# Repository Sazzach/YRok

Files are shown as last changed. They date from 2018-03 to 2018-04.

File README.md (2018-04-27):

## Building

To build the firmware, first download the GNU ARM toolchain from: https://developer.arm.com/open-source/gnu-toolchain/gnu-rm/downloads and extract it into the root directory for this project. Then enter the firmware directory and use Make to build the firmware.

To see a video demonstration of our final project: https://photos.app.goo.gl/VnfEDqI2edRJLxgh1

## Pinout

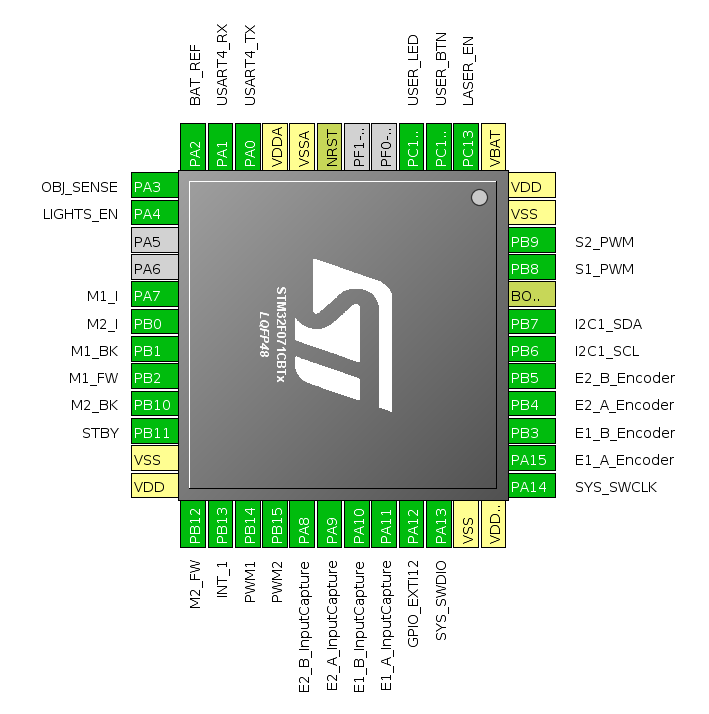
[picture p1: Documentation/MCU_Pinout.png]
STMF071CBTx pinout


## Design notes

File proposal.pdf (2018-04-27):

### CS5780 Project Proposal

Sam Zachary, Jeremy Whipple, Michael Zhang

Description:
We will build a robot that can balance on two parallel wheels with no external support. It will use a PID loop with an inertial measurement unit (LSM6DS3 IMU) (http://www.st.com/content/ccc/resource/technical/document/datasheet/a3/f5/4f/ae/8e/44/41/d7/DM00133076.pdf/files/DM00133076.pdf/jcr:content/translations/en.DM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) as input to control two motors (DAGU yellow gear motors). Each motor will potentially also be running its own PID loop to independently control speed. We will also have a custom designed microcontroller pcb (STM32F071) and motor encoder pcb. The motors, pcbs, and IMU will be mounted on a chassis fabricated out of laser cut wood and/or acrylic. Extraneous stretch goals include increased robustness, remote control, laser sensing.

The motor encoder PCB is mounted on the end of the DAGU gear motor. Each encoder has two IR reflectance sensors. These reflectance sensors sense transitions on a black and white encoder wheel mounted on the rear output shaft of the motor. To give a quadrature encoder signal, these sensors are positioned to emit signals 90 degrees out of phase from each other.

The custom microcontroller board collects all the necessary parts and peripherals (microprocessor, IMU, debug header, h-bridge, etc) and conforms to the Raspberry Pi HAT standard. It will connect to and control the two motors by reading from the motor encoders and running a PID control loop.

Implementation milestones:
1. PCB Design -- Sam
Solder board/make stencil for surface mount ICs -- Sam Simple board test (blinking LEDs) -- Michael
Design chassis - Sam
2. Communicate with IMU -- Jeremy
Serial communication -- Jeremy and Michael Correctly control motors -- Michael Construct chassis -- wood or acrylic -- Sam
3. Design algorithm to keep balance -- All
4. Tune algorithm -- All
Improve system reliability -- All

Functional block diagram:

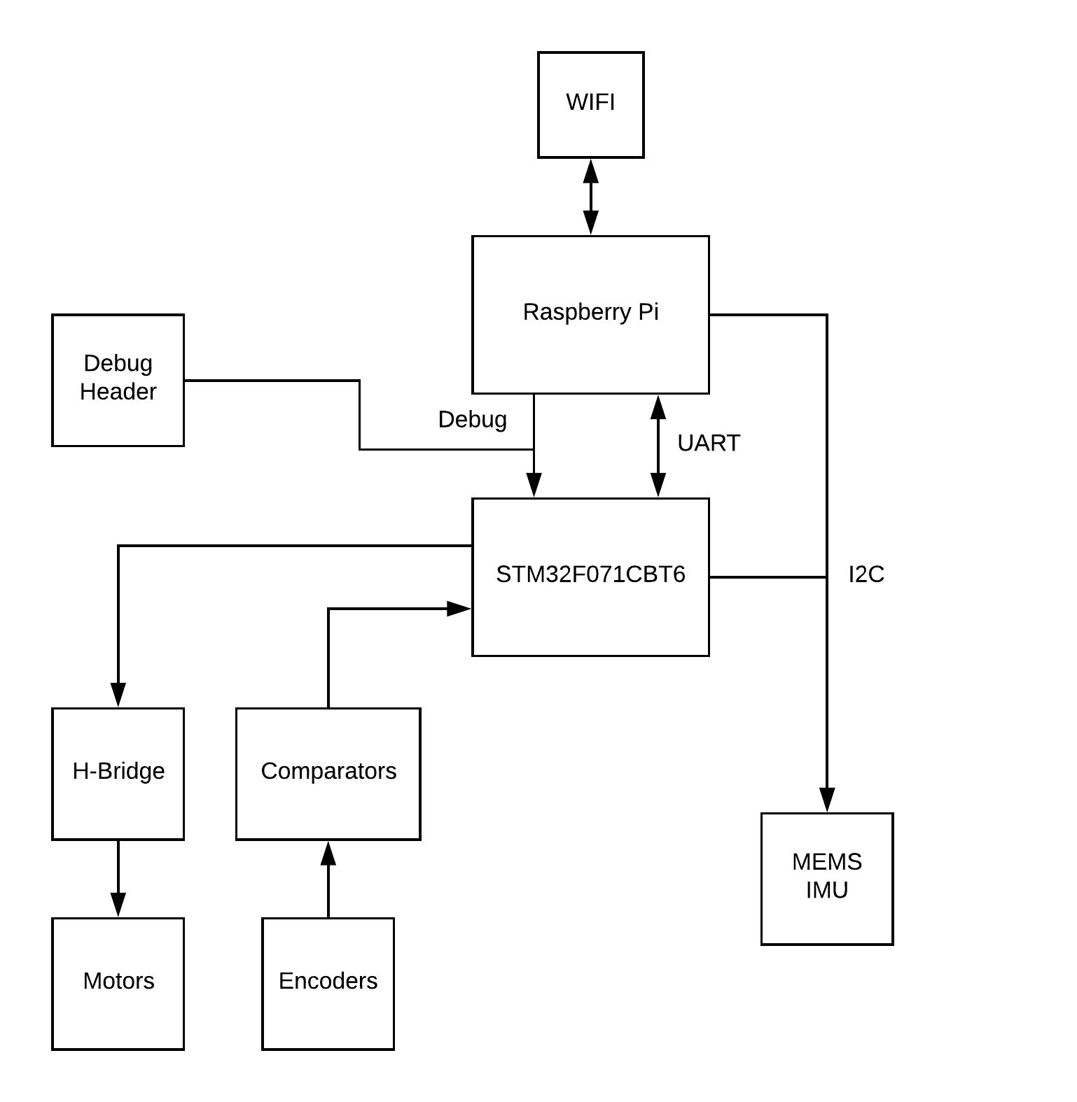
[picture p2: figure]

★ Raspberry pi passively used for wireless programming

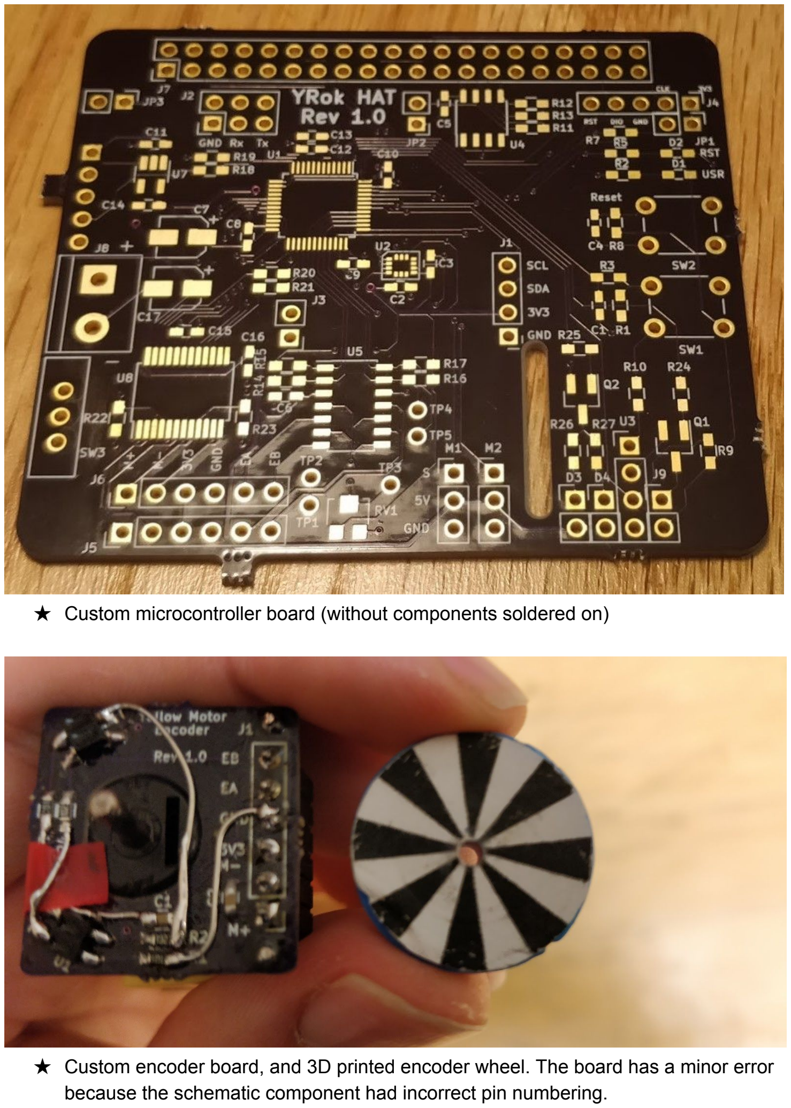
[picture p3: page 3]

★ Custom microcontroller board (without components soldered on)

★ Custom encoder board, and 3D printed encoder wheel. The board has a minor error because the schematic component had incorrect pin numbering.

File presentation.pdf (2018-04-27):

# CS 5780 Final Project YRok Balance Bot

## Sam Zachary, Jeremy Whipple, Michael Zhang

## Project overview

- Reverse pendulum robot
- Custom microcontroller PCB and encoder PCBs for the DAGU yellow gear motors
- IMU provides accelerometer and gyroscope data over I2C
- Using a PID control loop we stabilize the robot’s balance

## Objectives

- PCB Design (done)
- Solder board/make stencil for surface mount ICs (done)
- Simple board tests (done)
- Design chassis (done)
- Communicate with IMU (done)
- Serial communication (done)
- Correctly control motors (done)
- Construct chassis (done)
- Design algorithm to keep balance (done)
- Tune algorithm (done)
- Improve system reliability (in progress)

## Technicalities

- Custom board
- Raspberry Pi programming
- Chassis
- IMU interfacing
- Motor/encoder interfacing
- Complementary filter
- PID tuning

## Technicalities

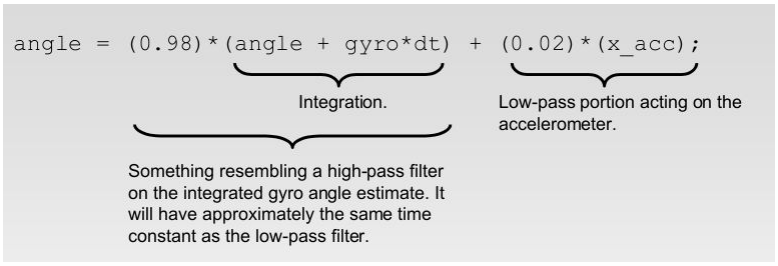
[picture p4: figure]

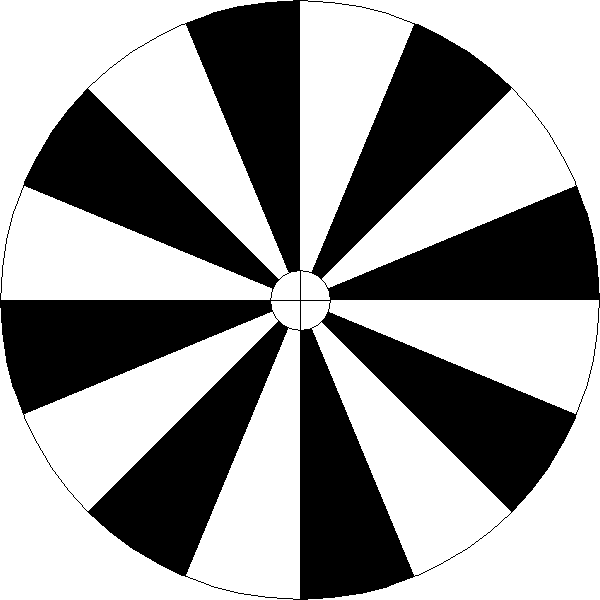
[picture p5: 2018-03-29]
Encoders/en_16.png

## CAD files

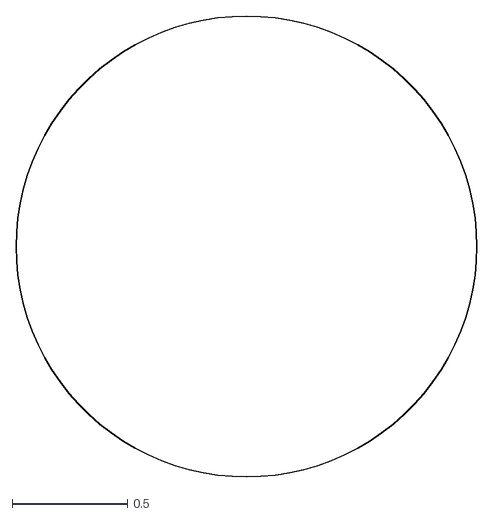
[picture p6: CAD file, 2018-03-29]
Control_Board/center.dxf
2.00 x 2.00

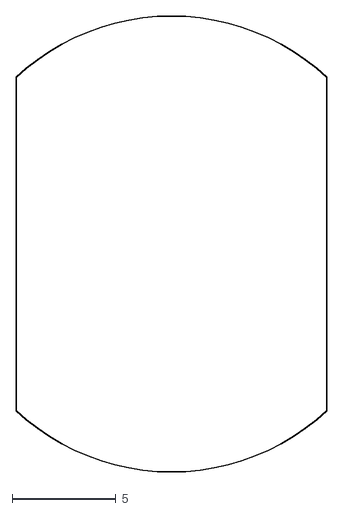
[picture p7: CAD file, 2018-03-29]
Encoders/motor_outline.dxf
15.0 x 22.0

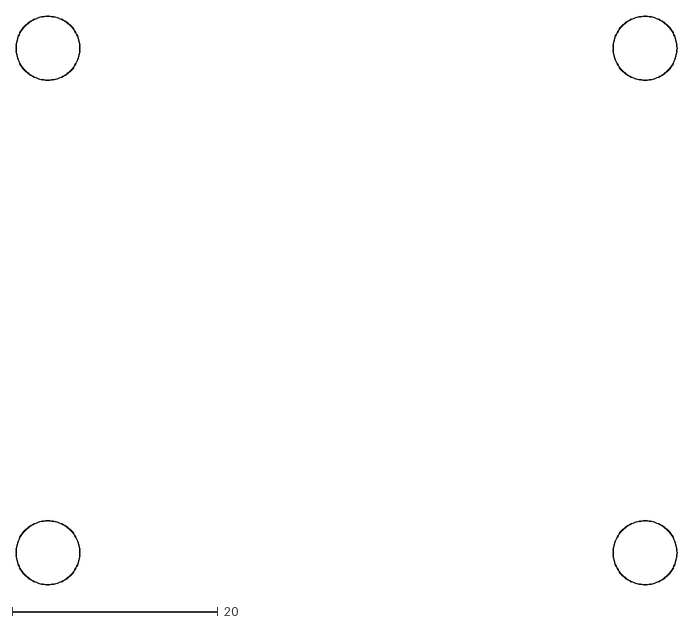
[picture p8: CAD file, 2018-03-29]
Control_Board/no_solder_mask.dxf
64.2 x 55.2

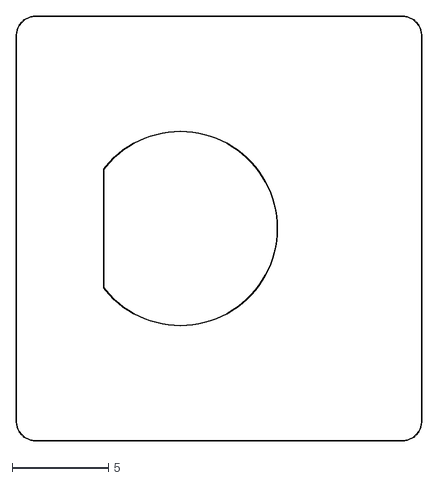
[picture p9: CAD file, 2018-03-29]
Encoders/encoder_edge_cuts.dxf
21.0 x 22.0

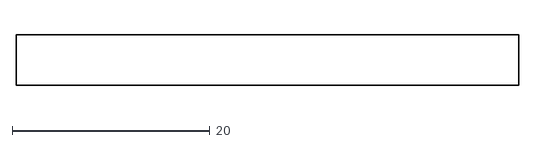
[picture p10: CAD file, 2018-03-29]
Control_Board/header_outline.dxf
50.8 x 5.08

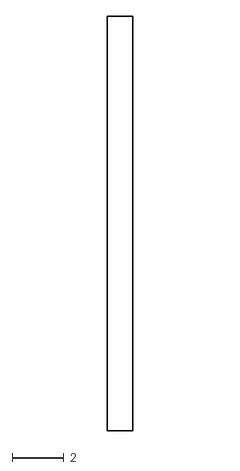
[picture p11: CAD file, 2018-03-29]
Encoders/tab_guide.dxf
1.00 x 16.0

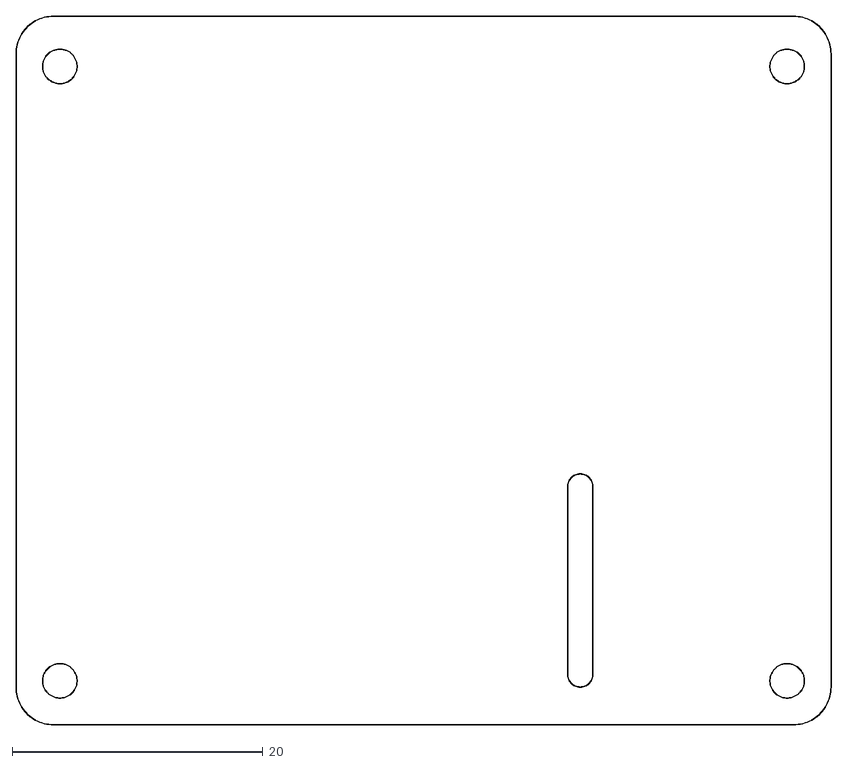
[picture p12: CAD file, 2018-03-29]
Control_Board/edge_cuts.dxf
65.0 x 56.5

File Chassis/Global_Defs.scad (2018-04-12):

eps = 1;
small_rad_frags = 50;

pi = 3.141592654;

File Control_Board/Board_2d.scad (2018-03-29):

$fn = 100;

origin = [0, 0];

board_width = 56.5;
board_length = 65;
board_corner_r = 3;

mount_d = 2.75;
mount_offset = 3.5;
mount_width_sep = 49;
mount_ring_d = 6.2;

cutout_r = 1;
cutout_len = 17;

camera_cutout_offset = [45, 11.5];

display_cutout_depth = 5;
display_cutout_offset = [0, 19.5];

//edge_cuts();
//solder_mask();
header_outline();
//board_center();

module edge_cuts() {
	difference() {
		board_outline();

		board_mount();
		camera_cutout();
		//display_cutout();
	}
}

module solder_mask() {
	board_mount(rings = true);
}

module header_outline() {
	translate([mount_offset + 29, mount_offset + mount_width_sep])
	square([50.8, 5.08], center = true);
}

module board_center() {
	translate([board_length/2, board_width/2])
	circle(r = 1);
}

module board_outline() {
	hull() {
		translate([0, 0])
		translate([board_corner_r, board_corner_r])
		circle(r = board_corner_r);

		translate([0, board_width])
		translate([board_corner_r, -board_corner_r])
		circle(r = board_corner_r);

		translate([board_length, 0])
		translate([-board_corner_r, board_corner_r])
		circle(r = board_corner_r);

		translate([board_length, board_width])
		translate([-board_corner_r, -board_corner_r])
		circle(r = board_corner_r);
	}
}

module board_mount(rings = false) {
	translate([0, 0])
	translate([mount_offset, mount_offset])
	if(rings) {
		circle(d = mount_ring_d);
	}
	else {
		circle(d = mount_d);
	}

	translate([board_length, 0])
	translate([-mount_offset, mount_offset])
	if(rings) {
		circle(d = mount_ring_d);
	}
	else {
		circle(d = mount_d);
	}

	translate([0, mount_width_sep])
	translate([mount_offset, mount_offset])
	if(rings) {
		circle(d = mount_ring_d);
	}
	else {
		#circle(d = mount_d);
	}

	translate([board_length, mount_width_sep])
	translate([-mount_offset, mount_offset])
	if(rings) {
		circle(d = mount_ring_d);
	}
	else {
		#circle(d = mount_d);
	}
}

module camera_cutout() {
	translate(camera_cutout_offset)
	hull() {
		translate([0, cutout_len/2 - cutout_r])
		circle(r = cutout_r);

		translate([0, -(cutout_len/2 - cutout_r)])
		circle(r = cutout_r);
	}
}

module display_cutout() {
	translate(display_cutout_offset) {
		hull() {
			translate([display_cutout_depth - cutout_r, 0])
			hull() {
				translate([0, cutout_r])
				circle(r = cutout_r);

				translate([0, cutout_len - cutout_r])
				circle(r = cutout_r);
			}

			translate([-1, 0])
			square([1, cutout_len]);
		}

		translate([0, -cutout_r])
		difference() {
			square([cutout_r, cutout_r]);

			translate([1, 0])
			circle(r = cutout_r);
		}

		translate([0, cutout_len])
		difference() {
			square([cutout_r, cutout_r]);

			translate([1, 1])
			circle(r = cutout_r);
		}
	}
}

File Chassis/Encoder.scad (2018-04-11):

use <BOSL/transforms.scad>
use <BOSL/shapes.scad>
use <BOSL/masks.scad>

use <Yellow_Motor.scad>
include <Global_Defs.scad>

use <../Encoders/encoder_edge_cuts.scad>

function encoder_wheel_d() = 20;
//function encoder_wheel_d() = ym_width();
function encoder_wheel_th() = 2;

segments = 16;
fancy_th = 0.05;

//encoder_wheel();

encoder_assembly();

module encoder_assembly() {
	yellow_motor();

	translate(ym_end_axle_pos())
	yrot(90)
	union() {
		zmove(5) {
			color([.1, .3, .7])
			encoder_wheel();

			down(fancy_th)
			fancy_wheel();
		}

		zmove(-ym_motor_end_th())
		zrot(90)
		sensor_mount();
	}
}

module encoder_wheel() {
	wheel_d = encoder_wheel_d();
	wheel_th = encoder_wheel_th();

	difference() {
		cylinder(h = wheel_th, d = wheel_d);

		down(eps/2)
		cylinder(h = wheel_th + eps, d = ym_end_axle_d(), $fn = small_rad_frags);
	}
}

module sensor_mount() {
	linear_extrude(encoder_board_th())
	encoder_edge_cuts();
}

module fancy_wheel() {
	difference() {
		for(i = [0:segments-1]) {
			zrot(i * 360/segments)
			up(fancy_th/2)
			color([i%2, i%2, i%2])
			render()
			angle_pie_mask(ang = 360/segments, h = fancy_th, d = encoder_wheel_d());
		}

		down(eps/2)
		cylinder(h = fancy_th + eps, d = ym_end_axle_d(), $fn = small_rad_frags);
	}
}

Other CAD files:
Chassis/Encoder_Wheel.scad
Chassis/Balance_Bot.scad
Chassis/Yellow_Motor.scad
Encoders/encoder_edge_cuts.scad

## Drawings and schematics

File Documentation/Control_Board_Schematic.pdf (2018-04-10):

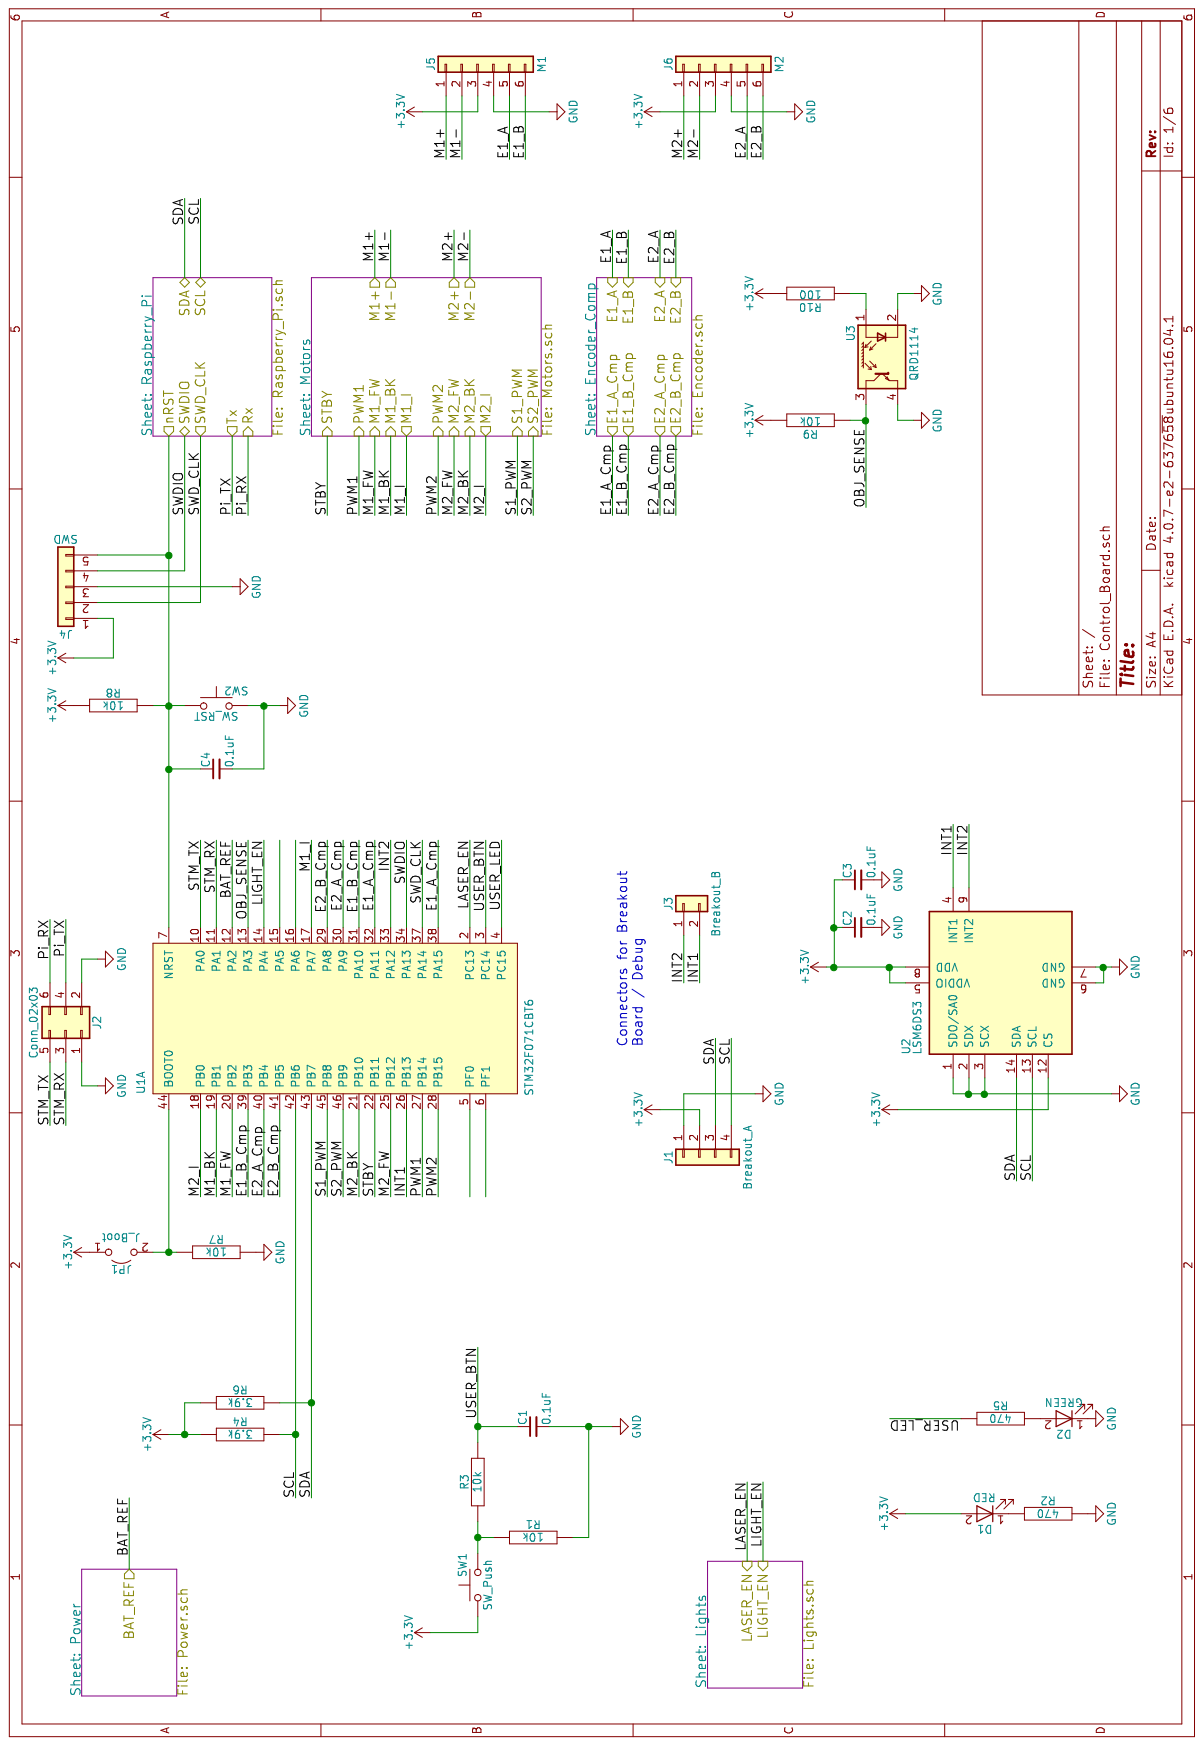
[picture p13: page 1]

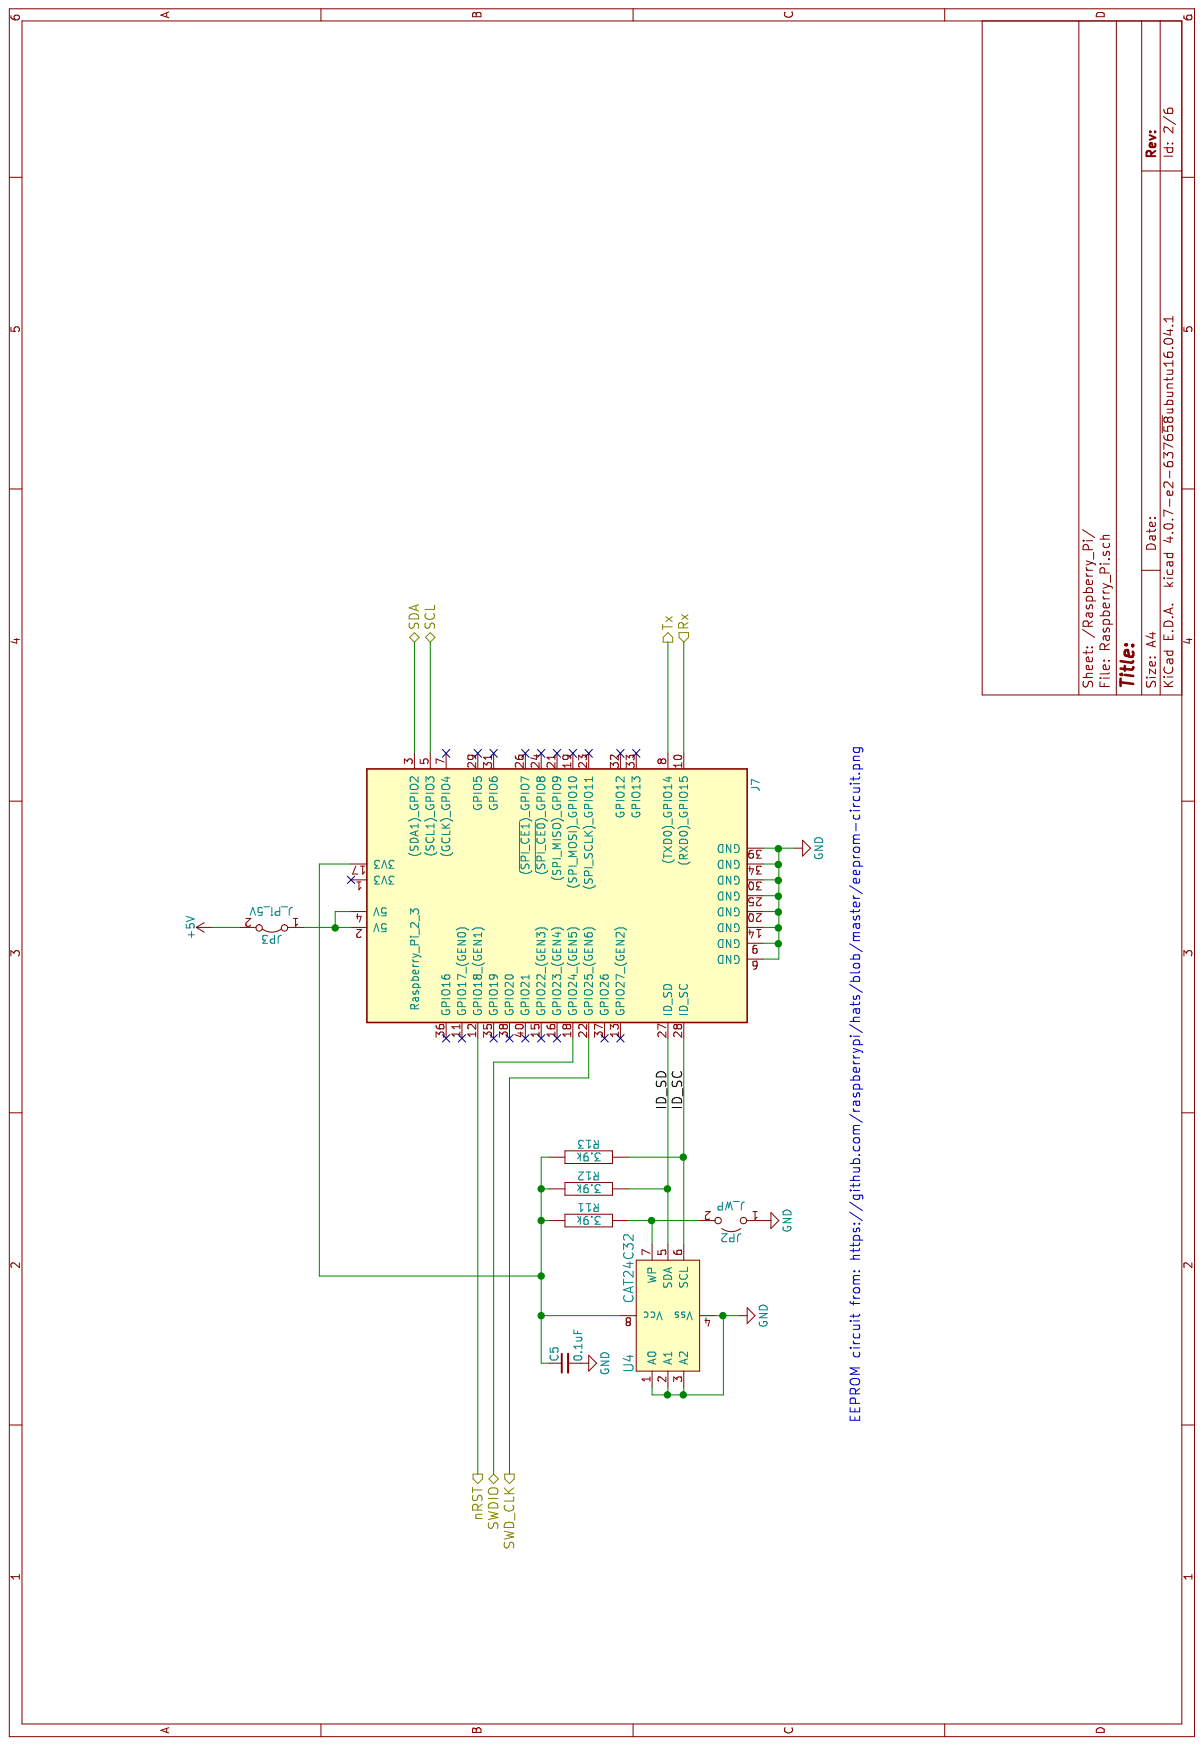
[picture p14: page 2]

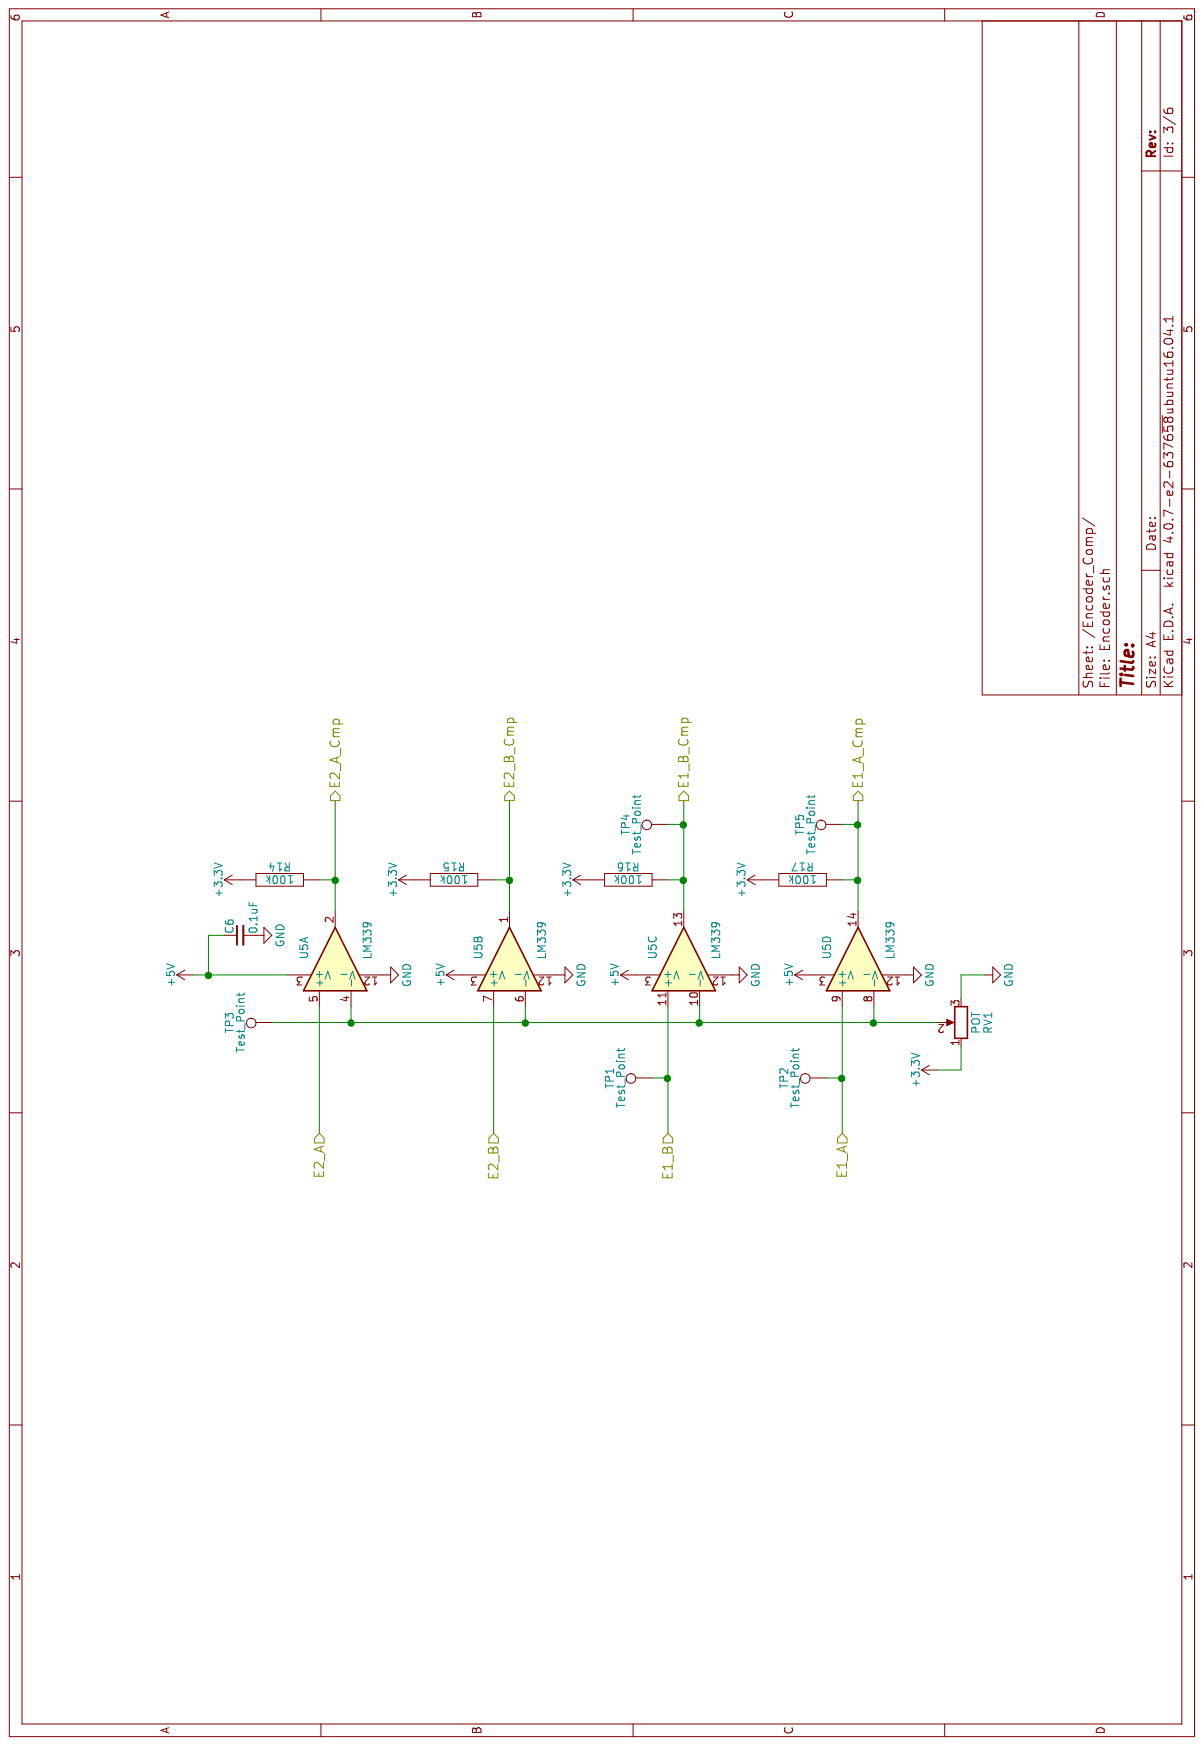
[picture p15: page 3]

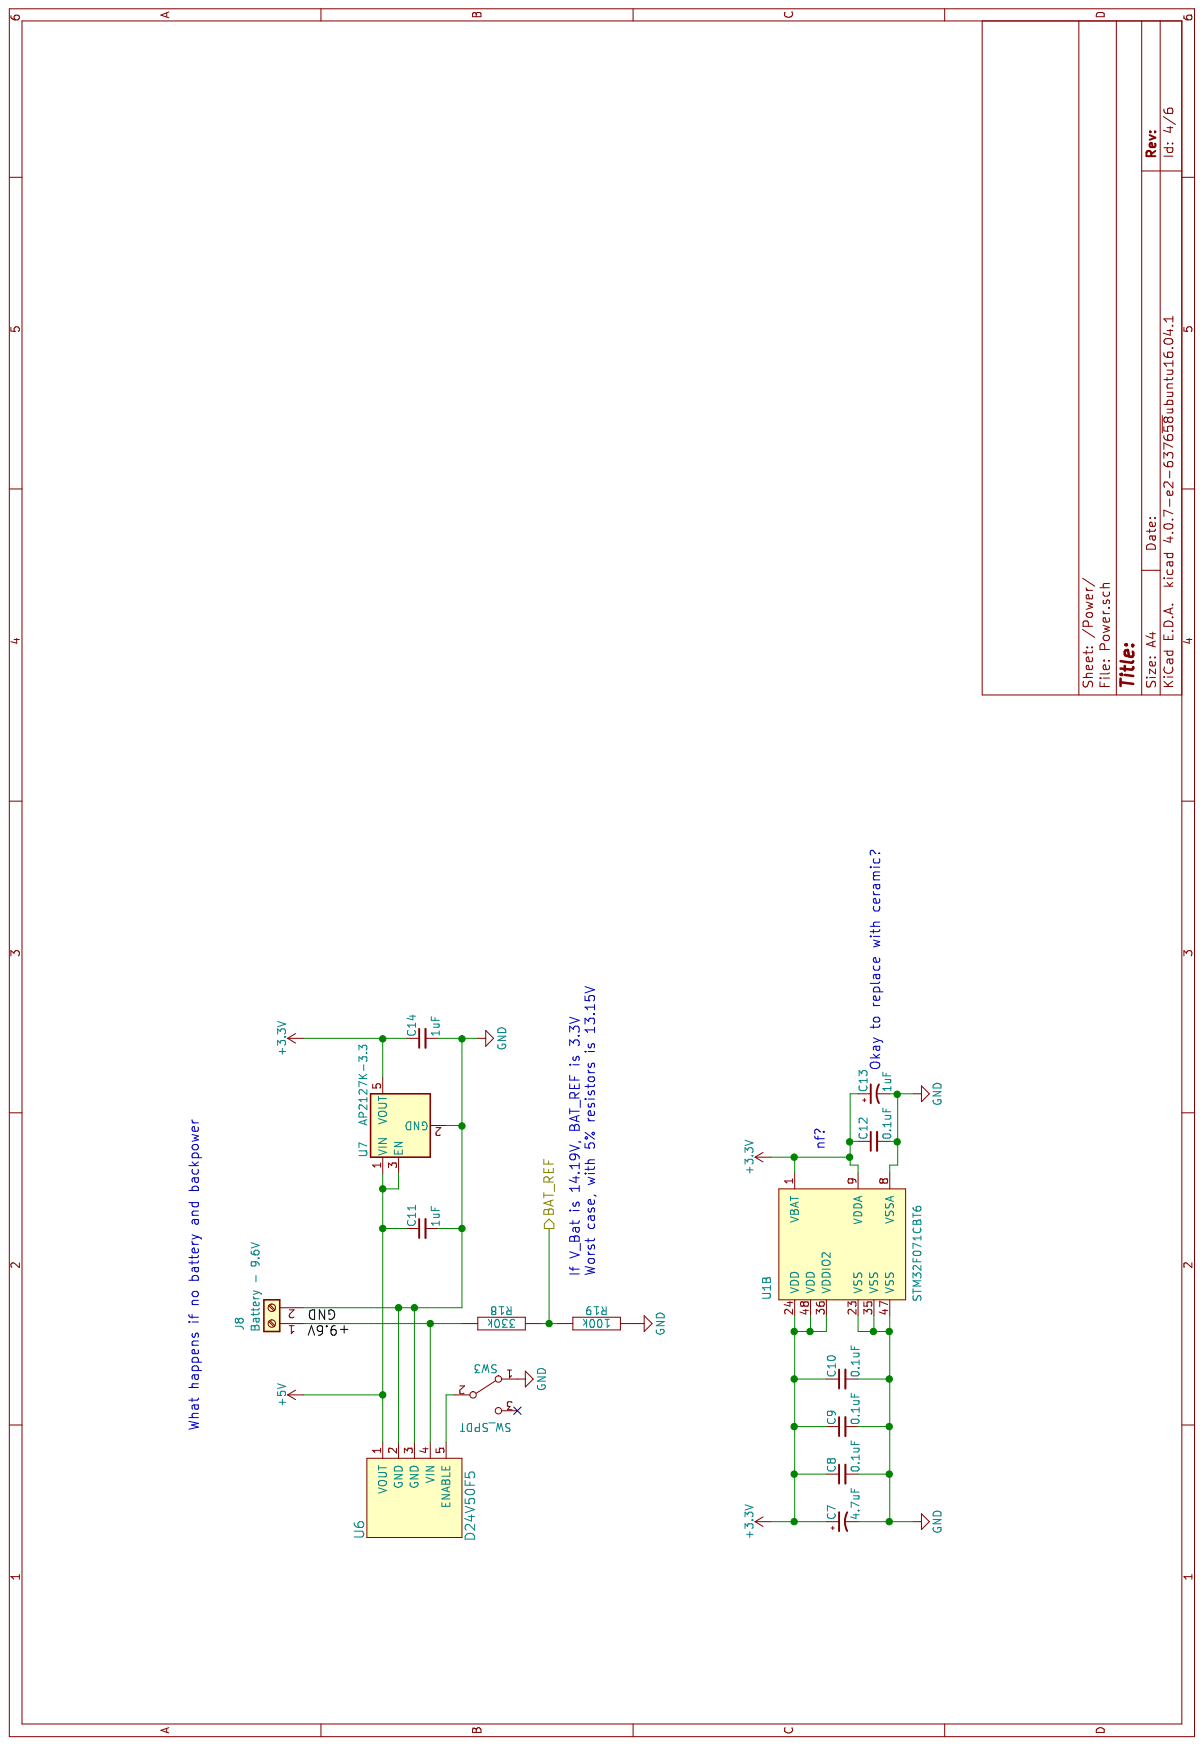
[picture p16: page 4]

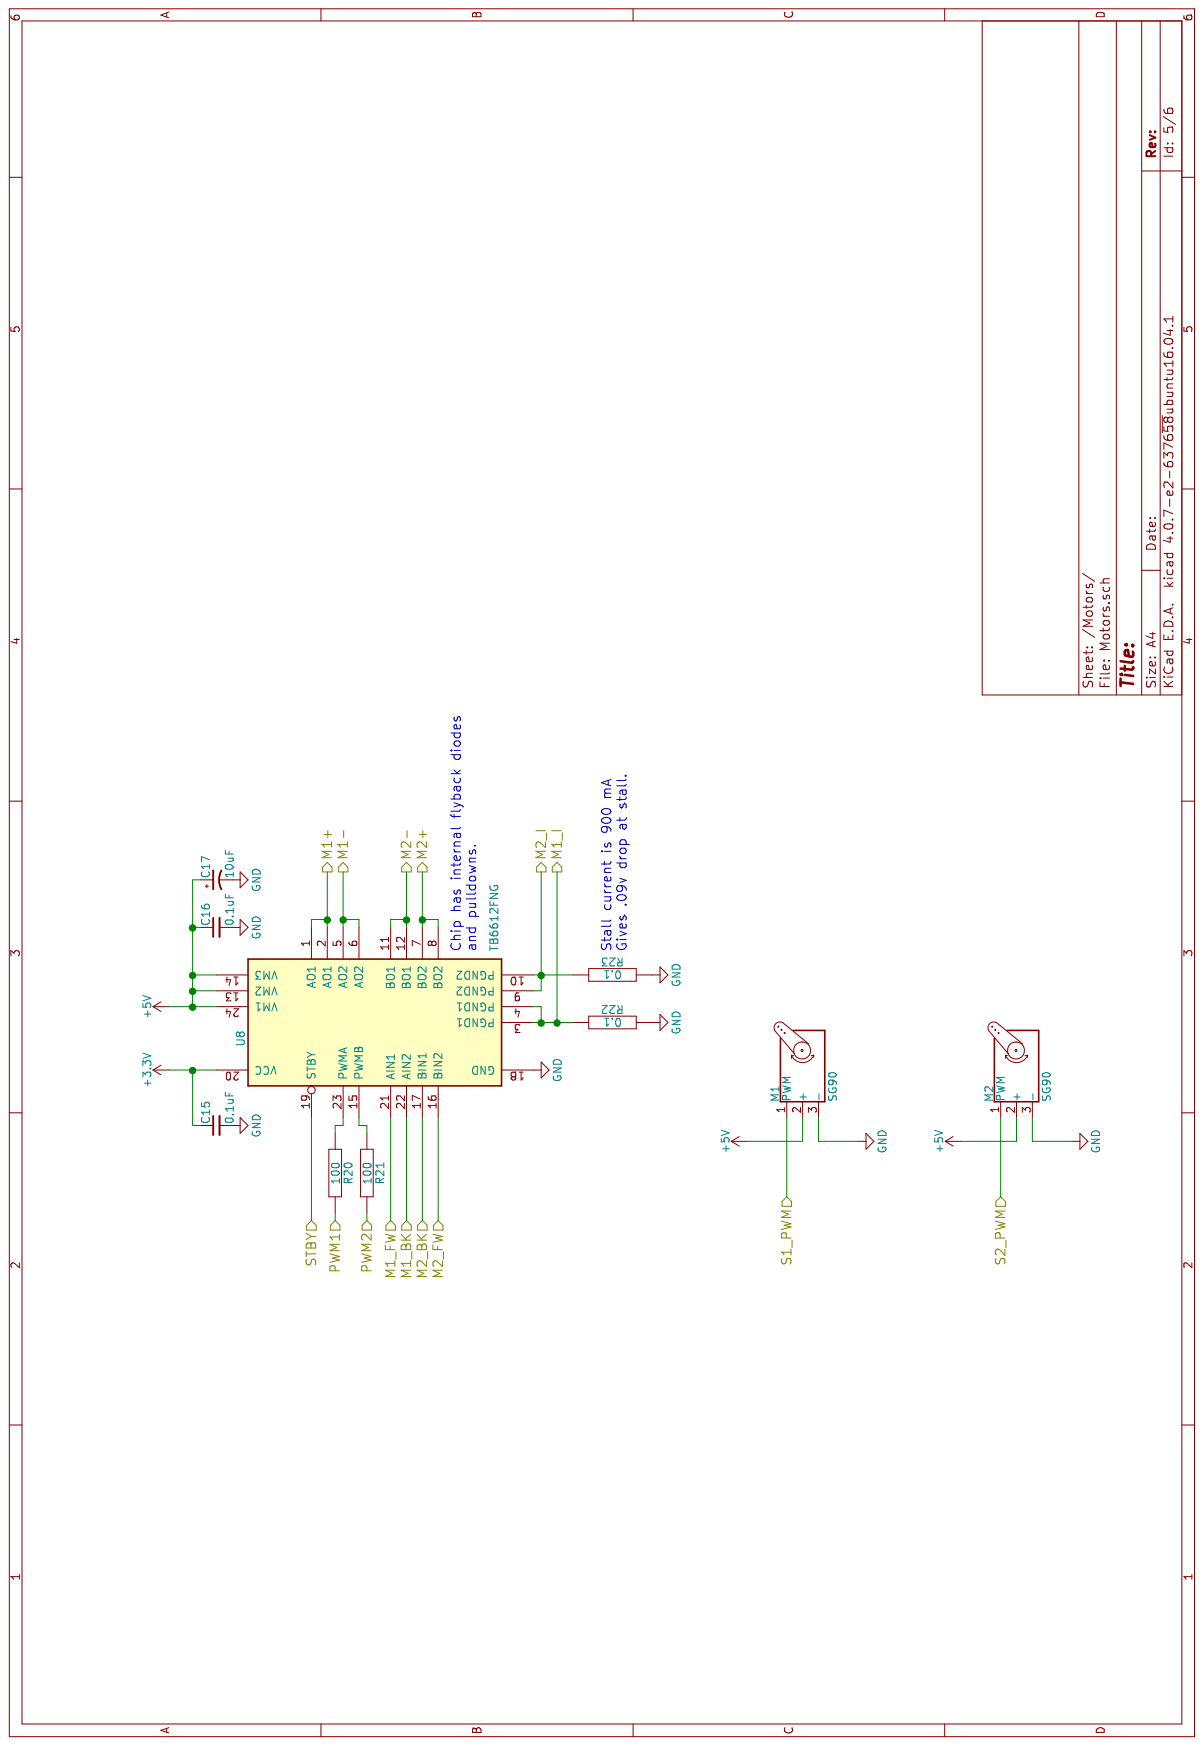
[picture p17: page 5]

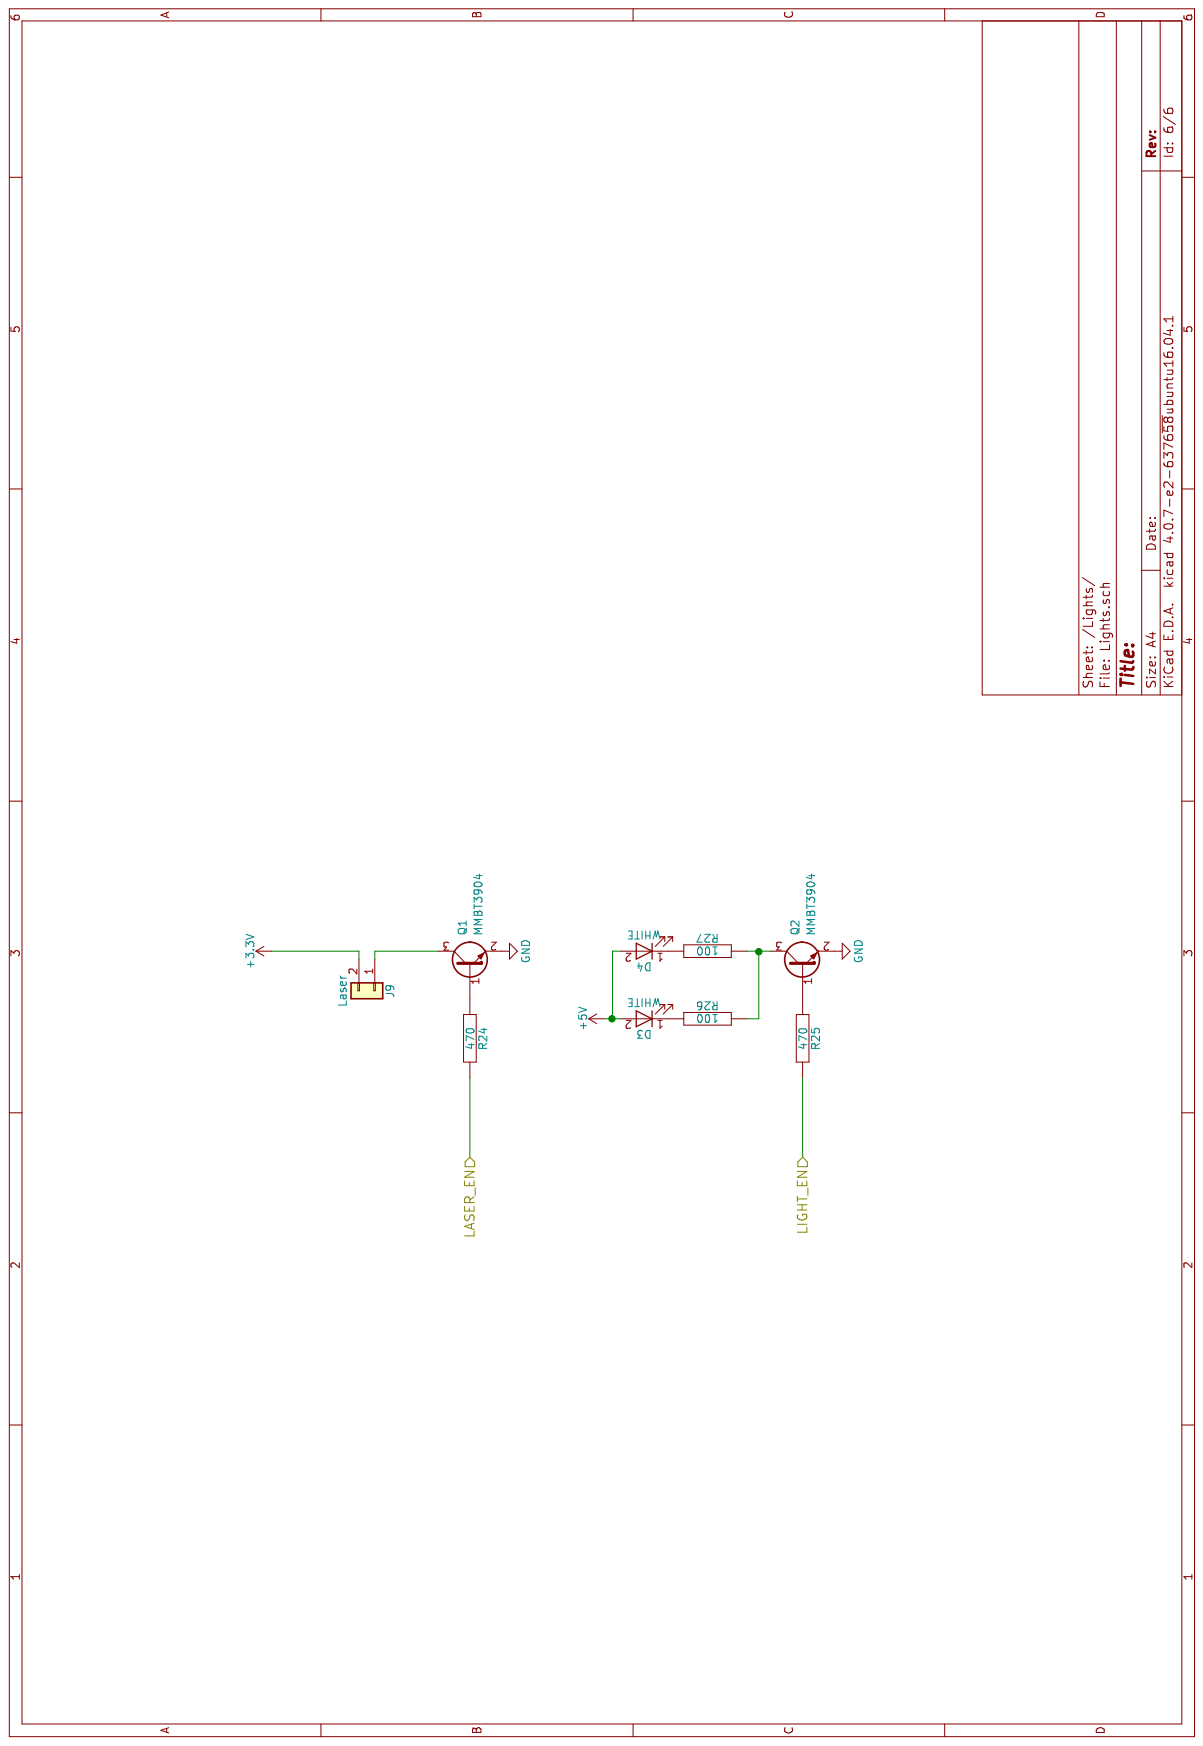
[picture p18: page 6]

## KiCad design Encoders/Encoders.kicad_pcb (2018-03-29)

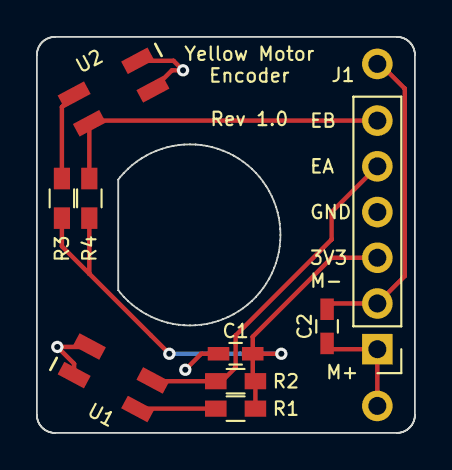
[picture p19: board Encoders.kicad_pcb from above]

Board: 2 copper layers, 21.0 x 22.0 mm, 10 parts (0 on the bottom side), 8 nets.

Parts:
C1, C2: 0.1uF; C_0603_HandSoldering
J1: Conn_01x06; Pin_Header_Straight_1x06_Pitch2.54mm
M1: Motor; Yellow_Motor
R1, R2, R3, R4: R; R_0603_HandSoldering
U1, U2: QRE1113GR

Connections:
+3V3: C1.1, J1.3, R1.1, R2.1, R3.1, R4.1
/E_A: J1.5, R2.2, U1.3
/E_B: J1.6, R4.2, U2.3
/M+: C2.1, J1.1, M1.1
/M-: C2.2, J1.2, M1.2
GND: C1.2, J1.4, U1.1, U1.4, U2.1, U2.4
unnamed: R1.2, U1.2
unnamed: R3.2, U2.2

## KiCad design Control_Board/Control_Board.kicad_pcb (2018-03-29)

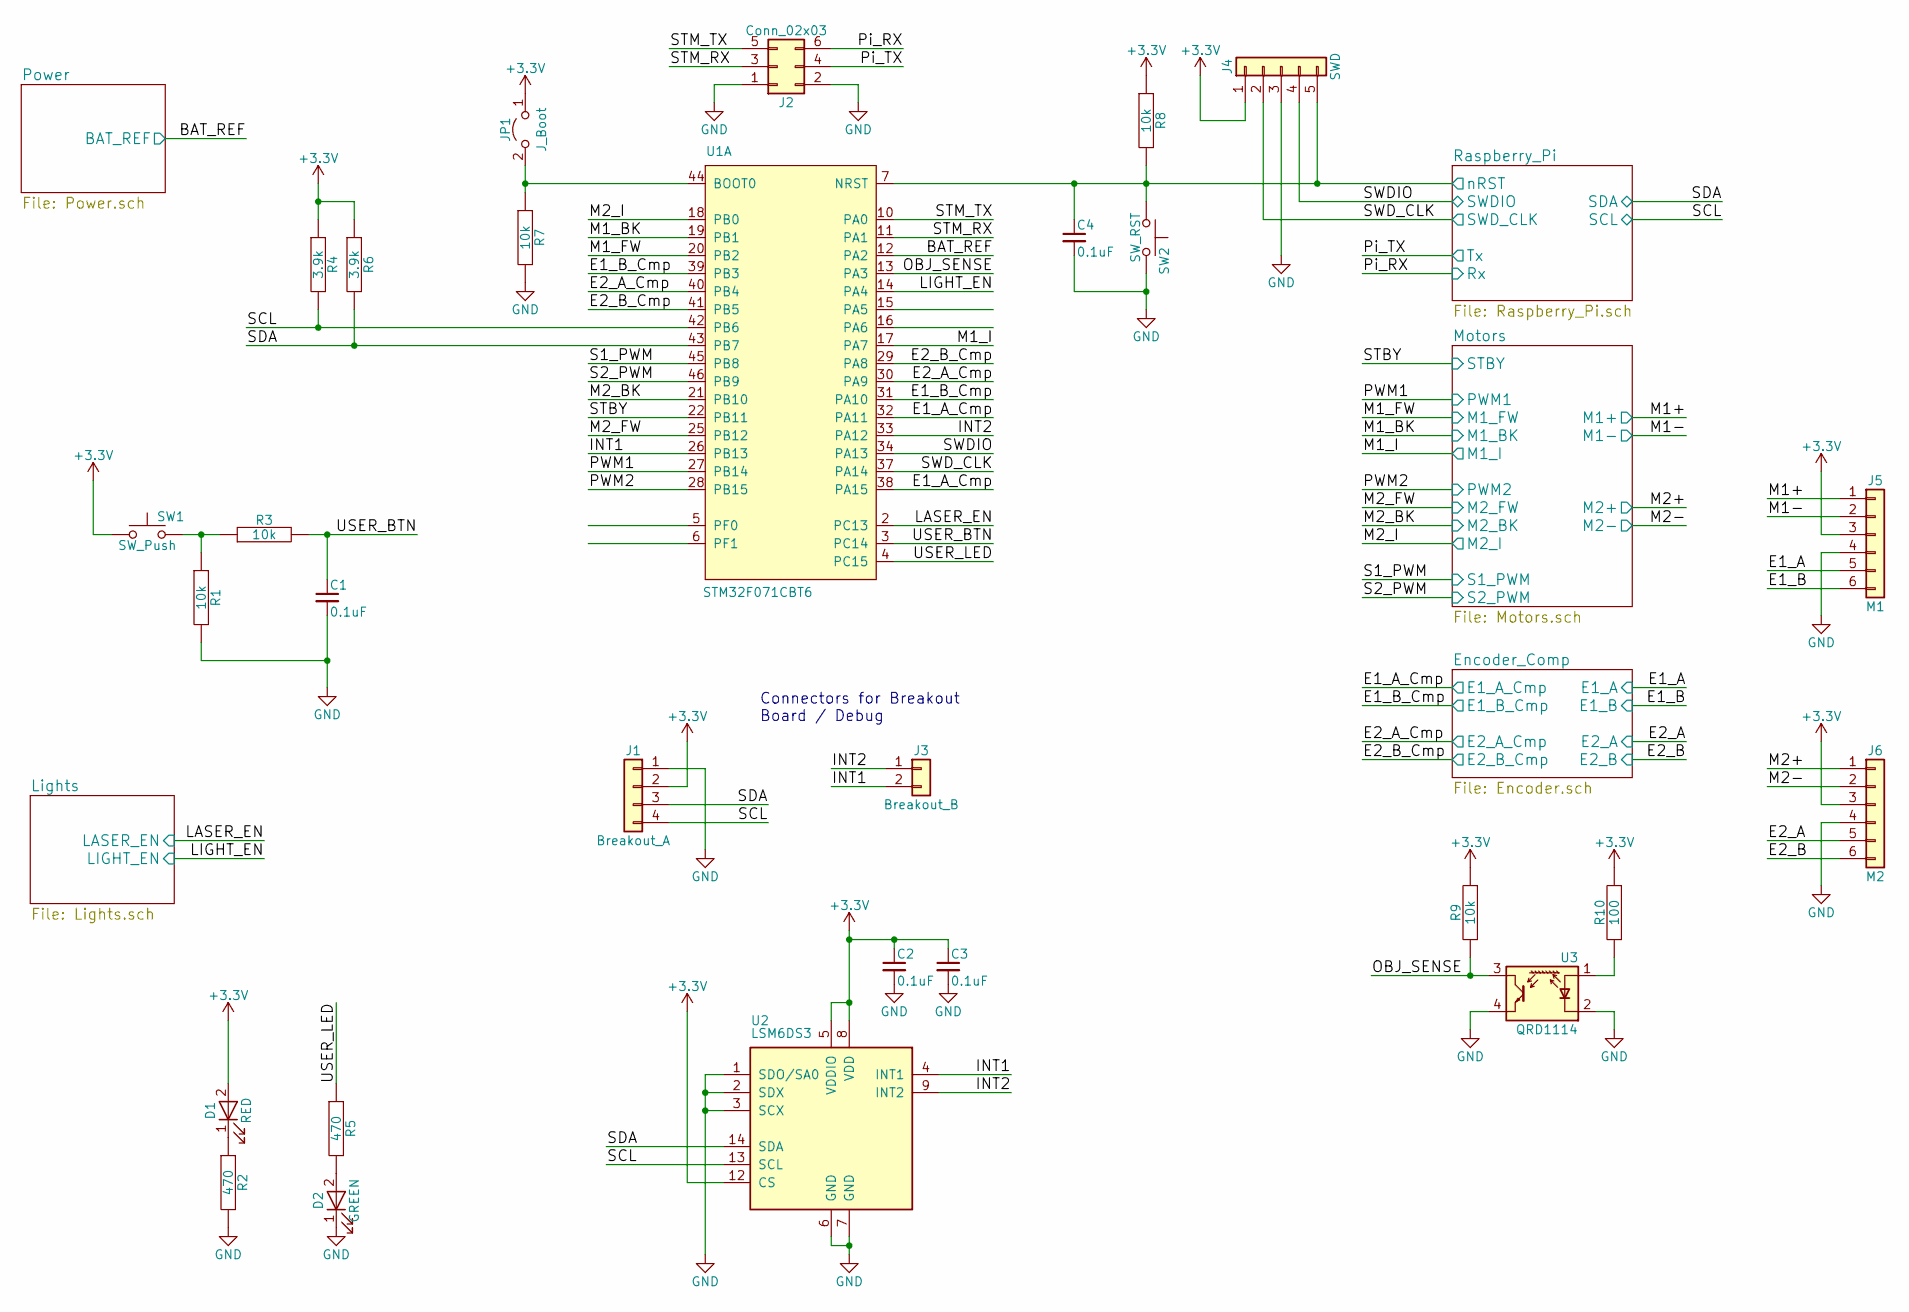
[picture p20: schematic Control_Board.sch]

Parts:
C1, C2, C3, C4: 0.1uF; C_0603_HandSoldering
D1: RED; LED_0603_HandSoldering
D2: GREEN; LED_0603_HandSoldering
J1: Breakout_A; Pin_Header_Straight_1x04_Pitch2.54mm
J2: Conn_02x03; Pin_Header_Straight_2x03_Pitch2.54mm
J3: Breakout_B; Pin_Header_Straight_1x02_Pitch2.54mm
J4: SWD; Pin_Header_Straight_1x05_Pitch2.54mm
J5: M1; Pin_Header_Straight_1x06_Pitch2.54mm
J6: M2; Pin_Header_Straight_1x06_Pitch2.54mm
JP1: J_Boot; Pin_Header_Straight_1x02_Pitch2.54mm
R1, R3, R7, R8, R9: 10k; R_0603_HandSoldering
R2, R5: 470; R_0603_HandSoldering
R4, R6: 3.9k; R_0603_HandSoldering
R10: 100; R_0603_HandSoldering
SW1: SW_Push; SW_PUSH_6mm
SW2: SW_RST; SW_PUSH_6mm
U1: STM32F071CBT6; LQFP-48_7x7mm_Pitch0.5mm
U2: LSM6DS3
U3: QRD1114; Pin_Header_Straight_1x04_Pitch2.54mm

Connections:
+3V3: C2.1, C3.1, D1.2 (A), J1.2, J4.1, J5.3, J6.3, JP1.1 (A), R4.1, R6.1, R8.1, R9.1, R10.1, SW1.1, U2.5 (VDDIO), U2.8 (VDD), U2.12 (CS); also elsewhere on the board
/BAT_REF: U1.12 (PA2); also elsewhere on the board
/E1_A: J5.5; also elsewhere on the board
/E1_A_Cmp: U1.32 (PA11), U1.38 (PA15); also elsewhere on the board
/E1_B: J5.6; also elsewhere on the board
/E1_B_Cmp: U1.31 (PA10), U1.39 (PB3); also elsewhere on the board
/E2_A: J6.5; also elsewhere on the board
/E2_A_Cmp: U1.30 (PA9), U1.40 (PB4); also elsewhere on the board
/E2_B: J6.6; also elsewhere on the board
/E2_B_Cmp: U1.29 (PA8), U1.41 (PB5); also elsewhere on the board
/INT1: J3.2, U1.26 (PB13), U2.4 (INT1)
/INT2: J3.1, U1.33 (PA12), U2.9 (INT2)
/LASER_EN: U1.2 (PC13); also elsewhere on the board
/LIGHT_EN: U1.14 (PA4); also elsewhere on the board
/M1+: J5.1; also elsewhere on the board
/M1-: J5.2; also elsewhere on the board
/M1_BK: U1.19 (PB1); also elsewhere on the board
/M1_FW: U1.20 (PB2); also elsewhere on the board
/M1_I: U1.17 (PA7); also elsewhere on the board
/M2+: J6.1; also elsewhere on the board
/M2-: J6.2; also elsewhere on the board
/M2_BK: U1.21 (PB10); also elsewhere on the board
/M2_FW: U1.25 (PB12); also elsewhere on the board
/M2_I: U1.18 (PB0); also elsewhere on the board
/OBJ_SENSE: R9.2, U1.13 (PA3), U3.3
/PWM1: U1.27 (PB14); also elsewhere on the board
/PWM2: U1.28 (PB15); also elsewhere on the board
/Pi_RX: J2.6; also elsewhere on the board
/Pi_TX: J2.4; also elsewhere on the board
/Raspberry_Pi/nRST: C4.1, J4.5, R8.2, SW2.1, U1.7 (NRST); also elsewhere on the board
/S1_PWM: U1.45 (PB8); also elsewhere on the board
/S2_PWM: U1.46 (PB9); also elsewhere on the board
/SCL: J1.4, R4.2, U1.42 (PB6), U2.13 (SCL); also elsewhere on the board
/SDA: J1.3, R6.2, U1.43 (PB7), U2.14 (SDA); also elsewhere on the board
/STBY: U1.22 (PB11); also elsewhere on the board
/STM_RX: J2.3, U1.11 (PA1)
/STM_TX: J2.5, U1.10 (PA0)
/SWDIO: J4.4, U1.34 (PA13); also elsewhere on the board
/SWD_CLK: J4.2, U1.37 (PA14); also elsewhere on the board
/USER_BTN: C1.1, R3.2, U1.3 (PC14)
/USER_LED: R5.1, U1.4 (PC15)
GND: C1.2, C2.2, C3.2, C4.2, D2.1 (K), J1.1, J2.1, J2.2, J4.3, J5.4, J6.4, R1.2, R2.2, R7.2, SW2.2, U2.1 (SDO/SA0), U2.2 (SDX), U2.3 (SCX), U2.6 (GND), U2.7 (GND), U3.2 (K), U3.4; also elsewhere on the board
unnamed: D1.1 (K), R2.1
unnamed: D2.2 (A), R5.2
unnamed: JP1.2 (B), R7.1, U1.44 (BOOT0)
unnamed: R1.1, R3.1, SW1.2
unnamed: R10.2, U3.1 (A)

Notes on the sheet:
Connectors for Breakout Board / Debug

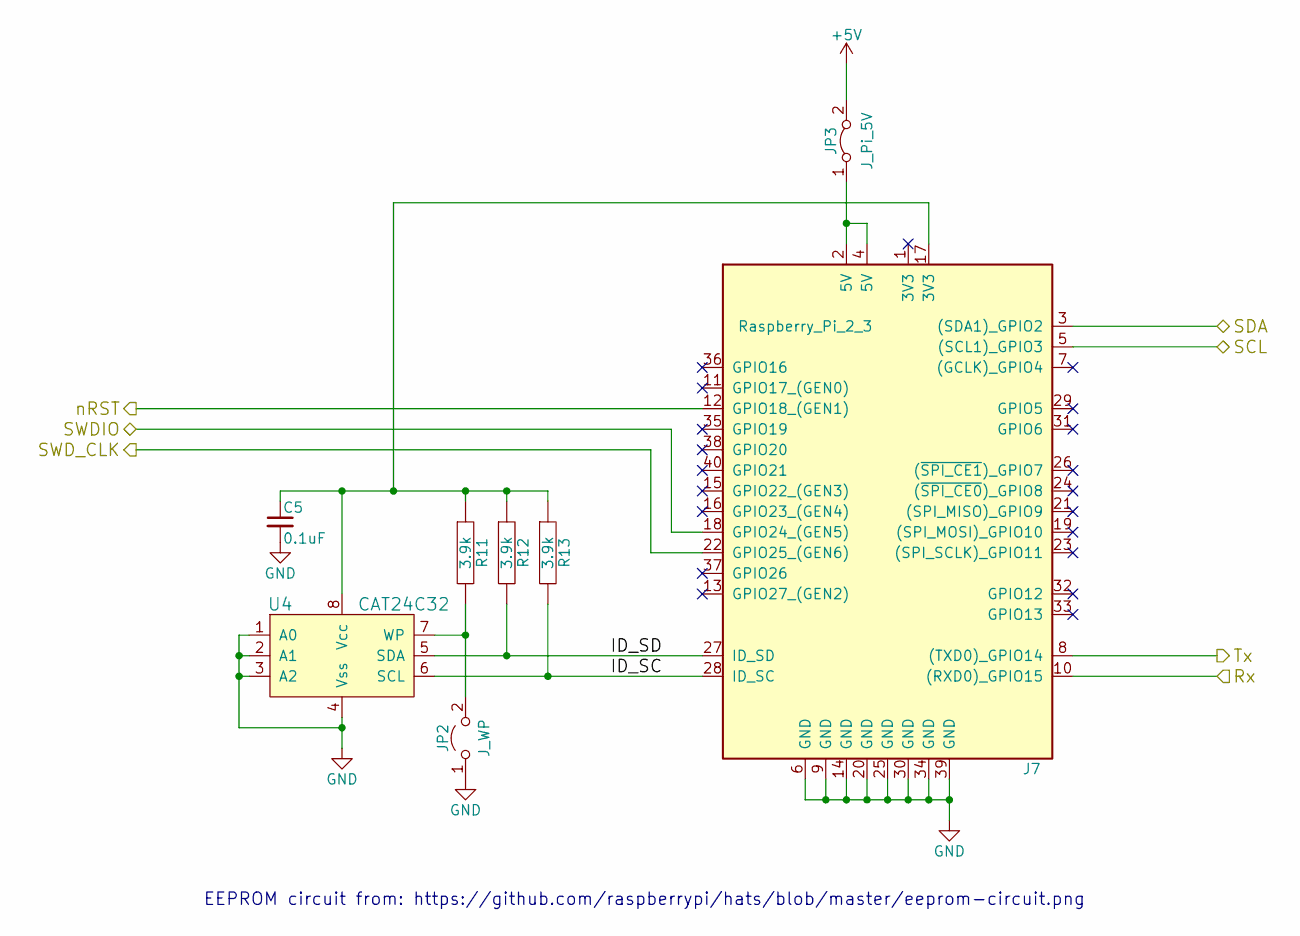
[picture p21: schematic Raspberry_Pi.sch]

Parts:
C5: 0.1uF; C_0603_HandSoldering
J7: Raspberry_Pi_2_3; Pin_Header_Straight_2x20_Pitch2.54mm
JP2: J_WP; Pin_Header_Straight_1x02_Pitch2.54mm
JP3: J_Pi_5V; Pin_Header_Straight_1x02_Pitch2.54mm
R11, R12, R13: 3.9k; R_0603_HandSoldering
U4: CAT24C32; SOIC-8_3.9x4.9mm_Pitch1.27mm

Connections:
+5V: JP3.2 (B); also elsewhere on the board
/Pi_RX: J7.10 ((RXD0)_GPIO15); also elsewhere on the board
/Pi_TX: J7.8 ((TXD0)_GPIO14); also elsewhere on the board
/Raspberry_Pi/ID_SC: J7.28 (ID_SC), R13.2, U4.6 (SCL)
/Raspberry_Pi/ID_SD: J7.27 (ID_SD), R12.2, U4.5 (SDA)
/Raspberry_Pi/nRST: J7.12 (GPIO18_(GEN1)); also elsewhere on the board
/SCL: J7.5 ((SCL1)_GPIO3); also elsewhere on the board
/SDA: J7.3 ((SDA1)_GPIO2); also elsewhere on the board
/SWDIO: J7.18 (GPIO24_(GEN5)); also elsewhere on the board
/SWD_CLK: J7.22 (GPIO25_(GEN6)); also elsewhere on the board
GND: C5.2, J7.6 (GND), J7.9 (GND), J7.14 (GND), J7.20 (GND), J7.25 (GND), J7.30 (GND), J7.34 (GND), J7.39 (GND), JP2.1 (A), U4.1 (A0), U4.2 (A1), U4.3 (A2), U4.4 (Vss); also elsewhere on the board
unnamed: C5.1, J7.17 (3V3), R11.1, R12.1, R13.1, U4.8 (Vcc)
unnamed: J7.2 (5V), J7.4 (5V), JP3.1 (A)
unnamed: JP2.2 (B), R11.2, U4.7 (WP)

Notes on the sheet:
EEPROM circuit from: https://github.com/raspberrypi/hats/blob/master/eeprom-circuit.png

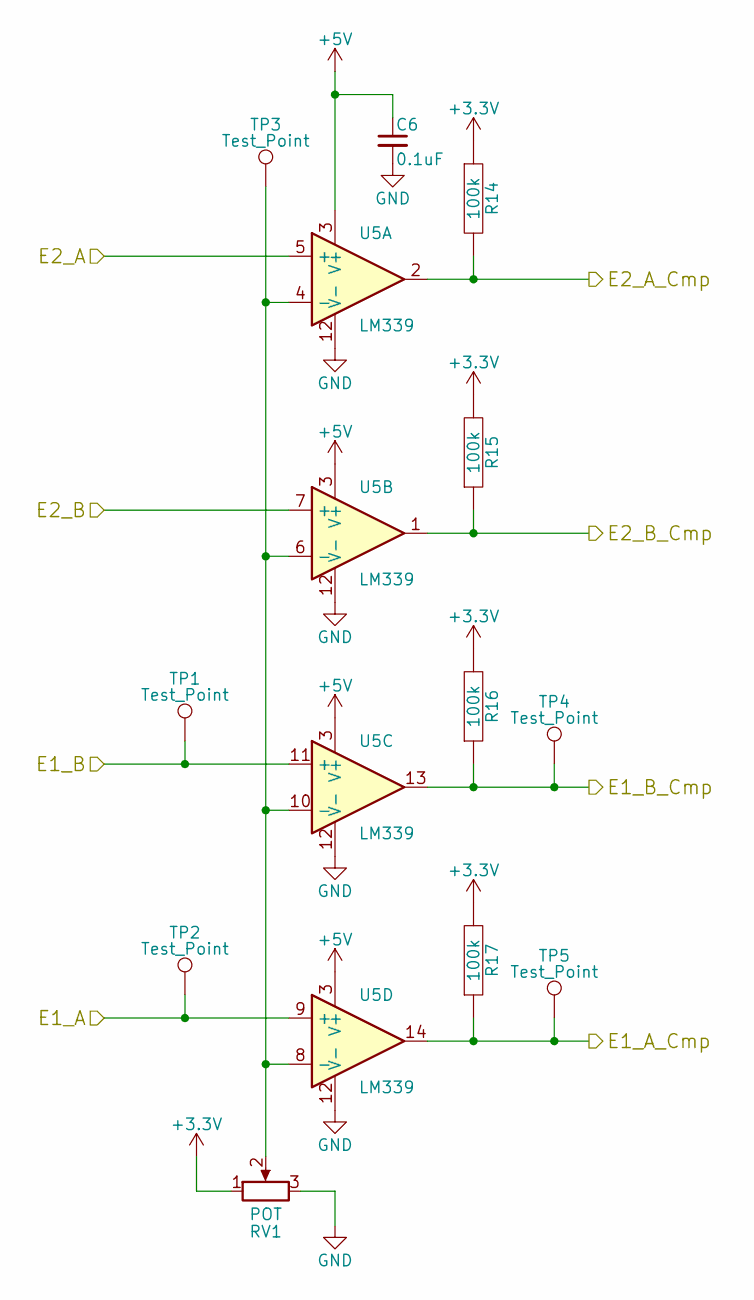
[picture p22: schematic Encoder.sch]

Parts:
C6: 0.1uF; C_0603_HandSoldering
R14, R15, R16, R17: 100k; R_0603_HandSoldering
RV1: POT; Pot_TC33X_2
TP1, TP2, TP3, TP4, TP5: Test_Point
U5: LM339; SOIC-14_3.9x8.7mm_Pitch1.27mm

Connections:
+3V3: R14.1, R15.2, R16.2, R17.2, RV1.1; also elsewhere on the board
+5V: C6.1, U5.3 (V+); also elsewhere on the board
/E1_A: TP2.1, U5.9 (+); also elsewhere on the board
/E1_A_Cmp: R17.1, TP5.1, U5.14; also elsewhere on the board
/E1_B: TP1.1, U5.11 (+); also elsewhere on the board
/E1_B_Cmp: R16.1, TP4.1, U5.13; also elsewhere on the board
/E2_A: U5.5 (+); also elsewhere on the board
/E2_A_Cmp: R14.2, U5.2; also elsewhere on the board
/E2_B: U5.7 (+); also elsewhere on the board
/E2_B_Cmp: R15.1, U5.1; also elsewhere on the board
GND: C6.2, RV1.3, U5.12 (V-); also elsewhere on the board
unnamed: RV1.2, TP3.1, U5.4 (-), U5.6 (-), U5.8 (-), U5.10 (-)

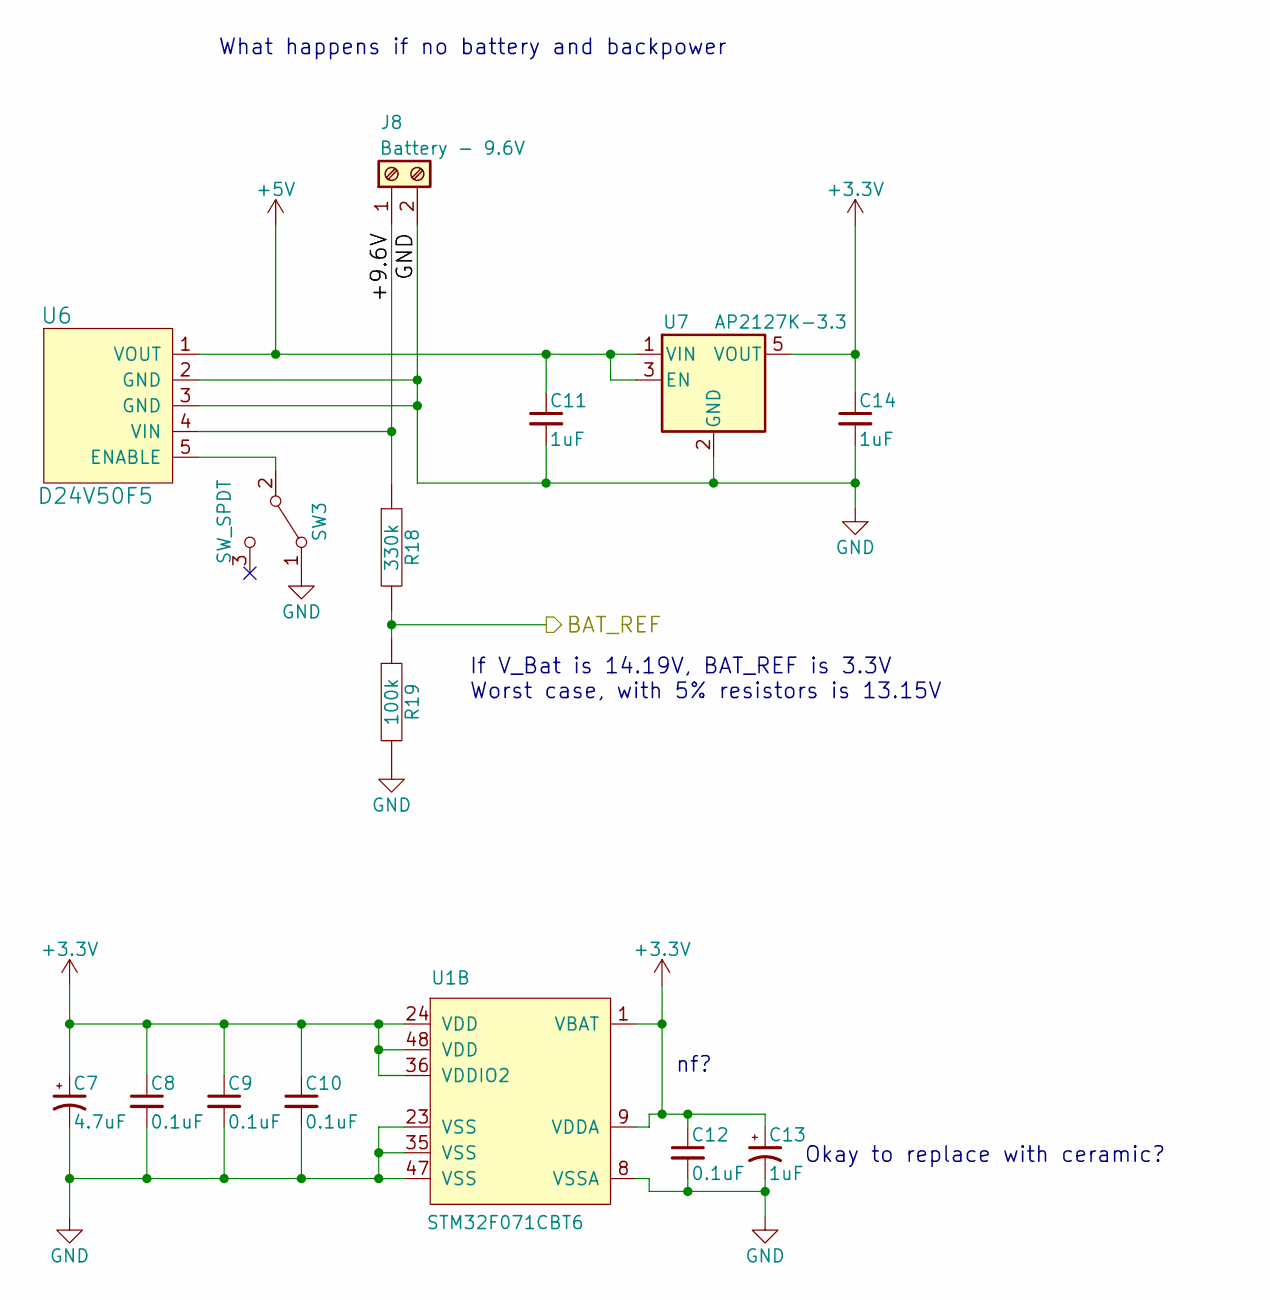
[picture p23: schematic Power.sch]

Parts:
C7: 4.7uF; CP_Elec_4x4.5
C8, C9, C10, C12: 0.1uF; C_0603_HandSoldering
C11, C13, C14: 1uF; C_0603_HandSoldering
J8: Battery - 9.6V; TerminalBlock_bornier-2_P5.08mm
R18: 330k; R_0603_HandSoldering
R19: 100k; R_0603_HandSoldering
SW3: SW_SPDT; SPDT_EG1218
U1: STM32F071CBT6; LQFP-48_7x7mm_Pitch0.5mm
U6: D24V50F5; Socket_Strip_Angled_1x05_Pitch2.54mm
U7: AP2127K-3.3; SOT-23-5_HandSoldering

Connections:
+3V3: C7.1, C8.1, C9.1, C10.1, C12.1, C13.1, C14.1, U1.1 (VBAT), U1.9 (VDDA), U1.24 (VDD), U1.36 (VDDIO2), U1.48 (VDD), U7.5 (VOUT); also elsewhere on the board
+5V: C11.1, U6.1 (VOUT), U7.1 (VIN), U7.3 (EN); also elsewhere on the board
/BAT_REF: R18.2, R19.1; also elsewhere on the board
/Power/+9.6V: J8.1, R18.1, U6.4 (VIN)
GND: C7.2, C8.2, C9.2, C10.2, C11.2, C12.2, C13.2, C14.2, J8.2, R19.2, SW3.1 (A), U1.8 (VSSA), U1.23 (VSS), U1.35 (VSS), U1.47 (VSS), U6.2 (GND), U6.3 (GND), U7.2 (GND); also elsewhere on the board
unnamed: SW3.2 (B), U6.5 (ENABLE)

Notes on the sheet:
If V_Bat is 14.19V, BAT_REF is 3.3V Worst case, with 5% resistors is 13.15V
What happens if no battery and backpower
Okay to replace with ceramic?
nf?

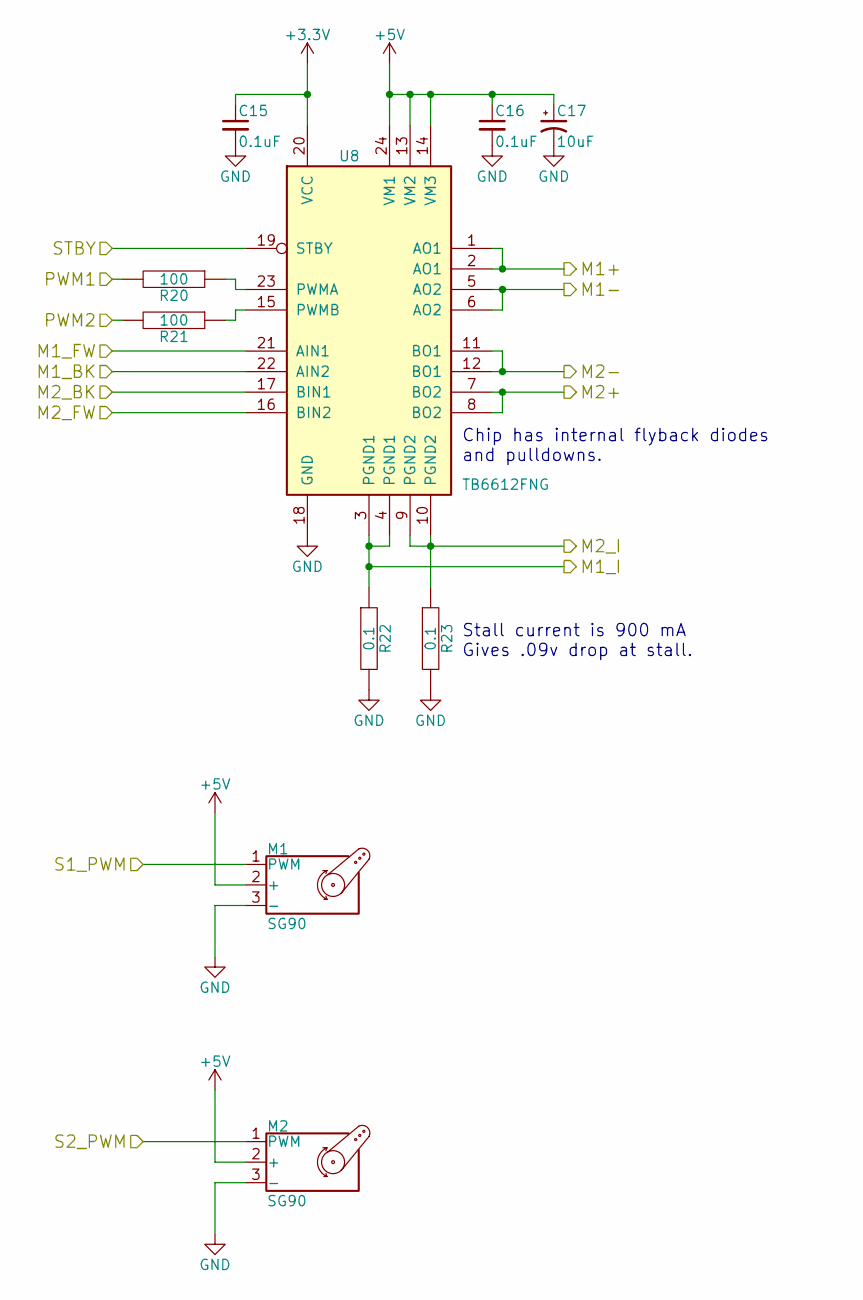
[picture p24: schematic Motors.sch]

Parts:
C15, C16: 0.1uF; C_0603_HandSoldering
C17: 10uF; CP_Elec_4x4.5
M1, M2: SG90; Pin_Header_Straight_1x03_Pitch2.54mm
R20, R21: 100; R_0603_HandSoldering
R22, R23: 0.1; R_0603_HandSoldering
U8: TB6612FNG; SSOP-24_5.3x8.2mm_Pitch0.65mm

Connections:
+3V3: C15.1, U8.20 (VCC); also elsewhere on the board
+5V: C16.1, C17.1, M1.2 (+), M2.2 (+), U8.13 (VM2), U8.14 (VM3), U8.24 (VM1); also elsewhere on the board
/M1+: U8.1 (AO1), U8.2 (AO1); also elsewhere on the board
/M1-: U8.5 (AO2), U8.6 (AO2); also elsewhere on the board
/M1_BK: U8.22 (AIN2); also elsewhere on the board
/M1_FW: U8.21 (AIN1); also elsewhere on the board
/M1_I: R22.1, U8.3 (PGND1), U8.4 (PGND1); also elsewhere on the board
/M2+: U8.7 (BO2), U8.8 (BO2); also elsewhere on the board
/M2-: U8.11 (BO1), U8.12 (BO1); also elsewhere on the board
/M2_BK: U8.17 (BIN1); also elsewhere on the board
/M2_FW: U8.16 (BIN2); also elsewhere on the board
/M2_I: R23.1, U8.9 (PGND2), U8.10 (PGND2); also elsewhere on the board
/PWM1: R20.2; also elsewhere on the board
/PWM2: R21.2; also elsewhere on the board
/S1_PWM: M1.1 (PWM); also elsewhere on the board
/S2_PWM: M2.1 (PWM); also elsewhere on the board
/STBY: U8.19 (STBY); also elsewhere on the board
GND: C15.2, C16.2, C17.2, M1.3 (-), M2.3 (-), R22.2, R23.2, U8.18 (GND); also elsewhere on the board
unnamed: R20.1, U8.23 (PWMA)
unnamed: R21.1, U8.15 (PWMB)

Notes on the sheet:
Chip has internal flyback diodes and pulldowns.
Stall current is 900 mA Gives .09v drop at stall.

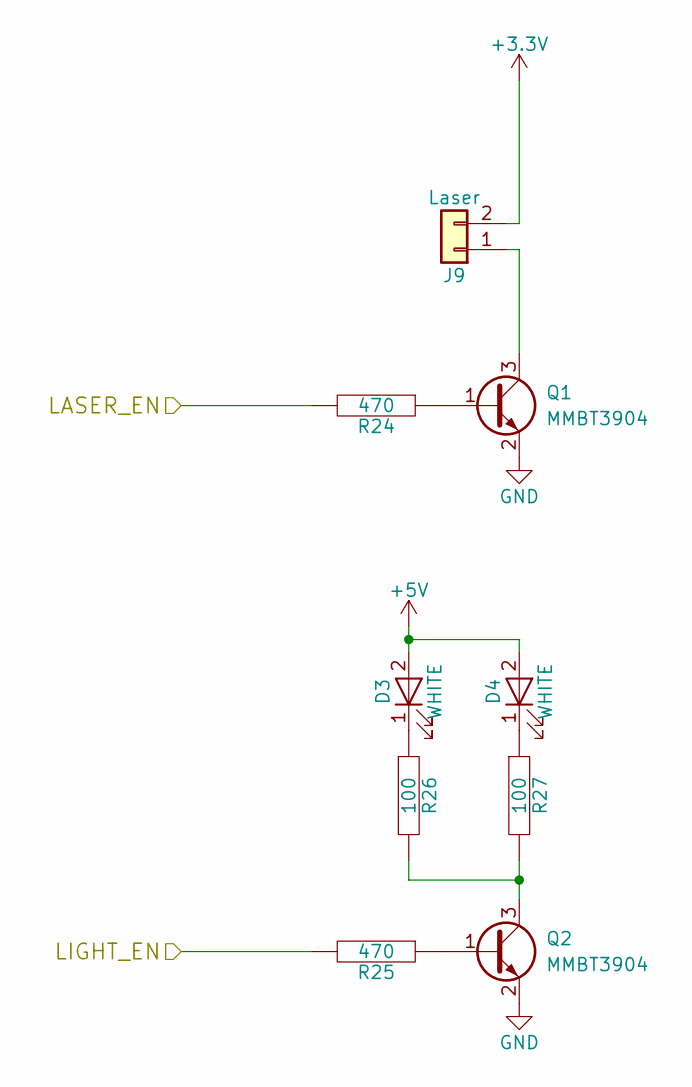
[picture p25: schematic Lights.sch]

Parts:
D3, D4: WHITE; Pin_Header_Straight_1x02_Pitch2.54mm
J9: Laser; Pin_Header_Straight_1x02_Pitch2.54mm
Q1, Q2: MMBT3904; SOT-23_Handsoldering
R24, R25: 470; R_0603_HandSoldering
R26, R27: 100; R_0603_HandSoldering

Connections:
+3V3: J9.2; also elsewhere on the board
+5V: D3.2 (A), D4.2 (A); also elsewhere on the board
/LASER_EN: R24.2; also elsewhere on the board
/LIGHT_EN: R25.2; also elsewhere on the board
GND: Q1.2 (E), Q2.2 (E); also elsewhere on the board
unnamed: D3.1 (K), R26.1
unnamed: D4.1 (K), R27.1
unnamed: J9.1, Q1.3 (C)
unnamed: Q1.1 (B), R24.1
unnamed: Q2.1 (B), R25.1
unnamed: Q2.3 (C), R26.2, R27.2

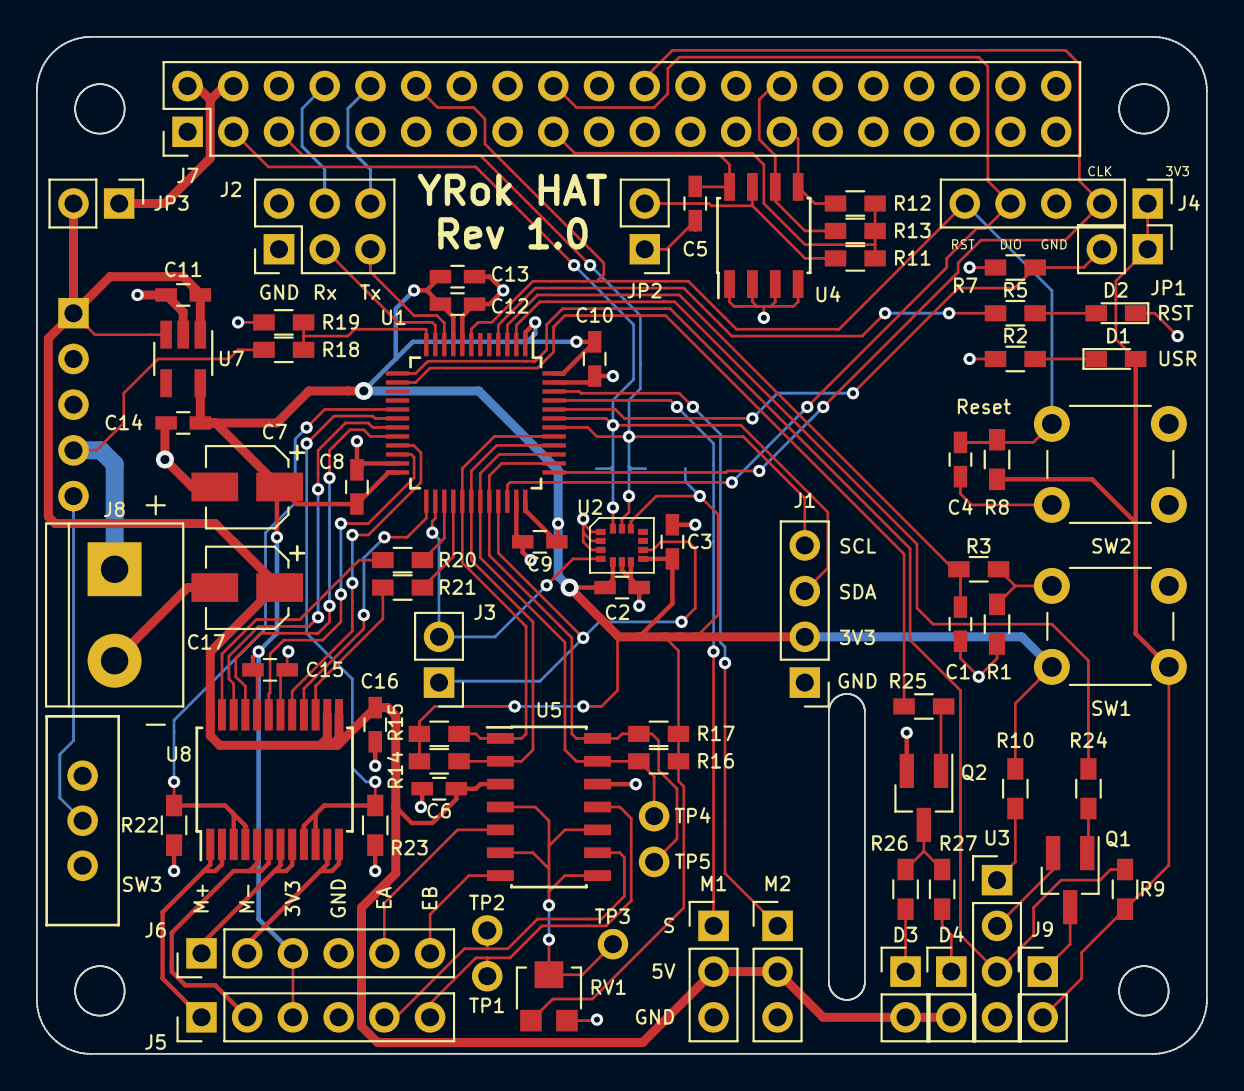
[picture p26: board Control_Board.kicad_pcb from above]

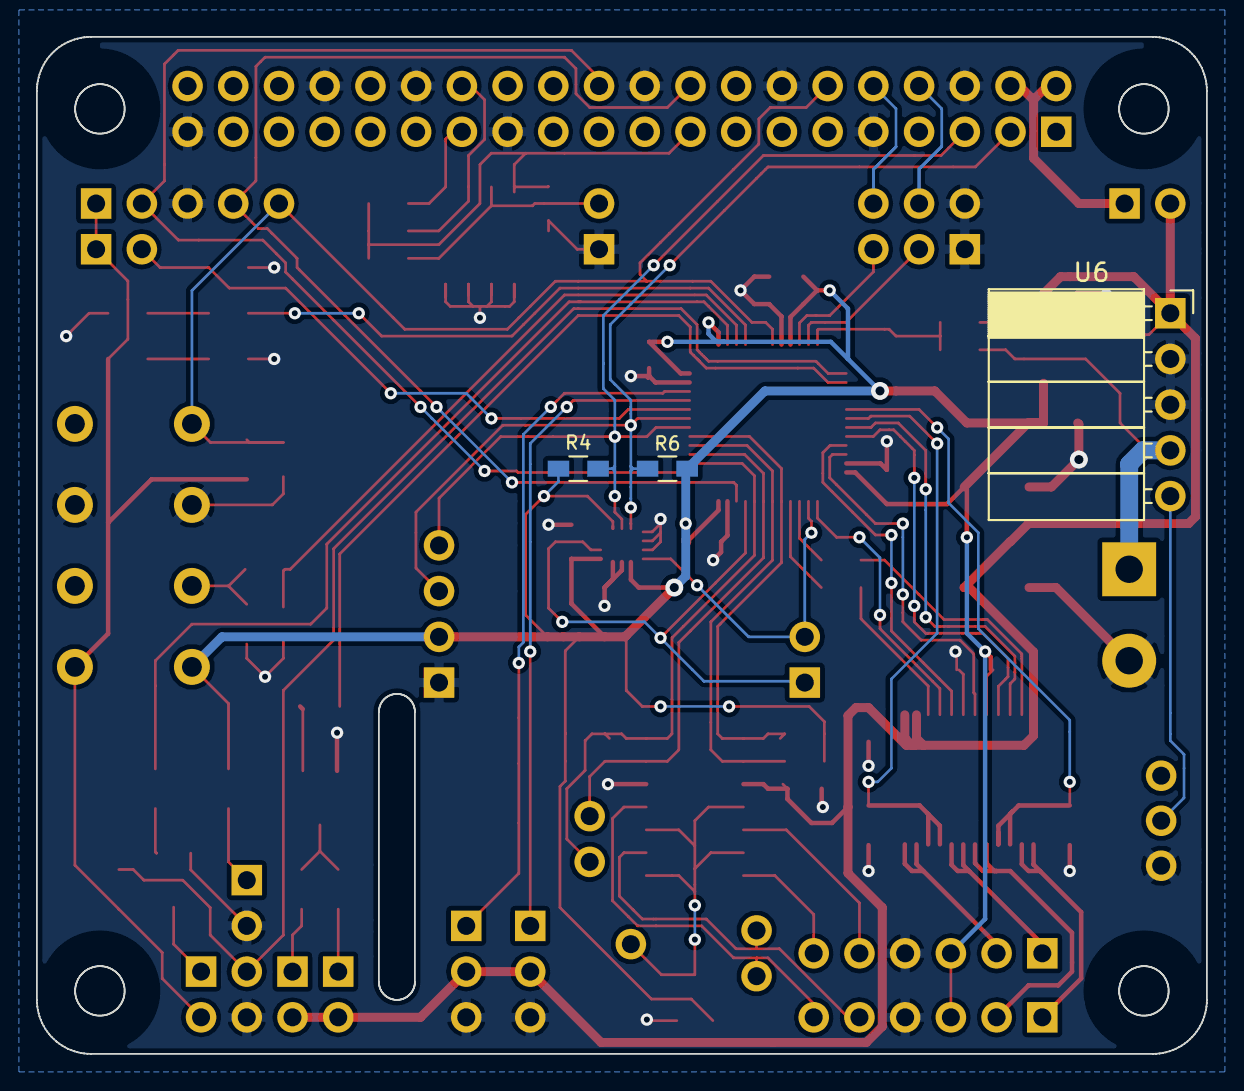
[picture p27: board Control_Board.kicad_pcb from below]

Board: 2 copper layers, 65.0 x 56.5 mm, 81 parts (3 on the bottom side), 64 nets.

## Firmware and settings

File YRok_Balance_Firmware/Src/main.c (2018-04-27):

/**
  ******************************************************************************
  * File Name          : main.c
  * Description        : Main program body
  ******************************************************************************
  ** This notice applies to any and all portions of this file
  * that are not between comment pairs USER CODE BEGIN and
  * USER CODE END. Other portions of this file, whether 
  * inserted by the user or by software development tools
  * are owned by their respective copyright owners.
  *
  * COPYRIGHT(c) 2018 STMicroelectronics
  *
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
  ******************************************************************************
  */

/* Includes ------------------------------------------------------------------*/
#include "main.h"
#include "stm32f0xx_hal.h"

/* USER CODE BEGIN Includes */
#include "imu_control.h"
#include "uart.h"
#include "pid.h"
#include "motor.h"
/* USER CODE END Includes */

TIM_HandleTypeDef htim2;
TIM_HandleTypeDef htim3;

/* USER CODE BEGIN PV */

/* USER CODE END PV */

void SystemClock_Config(void);
static void MX_GPIO_Init(void);
static void MX_TIM2_Init(void);
static void MX_TIM3_Init(void);

/* USER CODE BEGIN PFP */

/* USER CODE END PFP */

/* USER CODE BEGIN 0 */

void init_usr_led()
{
  // enable the peripheral
  RCC->AHBENR |= RCC_AHBENR_GPIOCEN;

  // init the usr led
  GPIOC->MODER |= (0x1 << 15*2);
  GPIOC->ODR |= (0x1 << 15);
}

void wait_for_button()
{
  // wait for a button press
  RCC->AHBENR |= RCC_AHBENR_GPIOCEN;

  while(!(GPIOC->IDR & (0x1 << 14)));
}

/* USER CODE END 0 */

int main(void)
{

  char who_am;
  HAL_Init();
  SystemClock_Config();

  // init usr led
  init_usr_led();

  // init uart
  init_uart();
  transmit_string("RESET\r\n");

  MX_GPIO_Init();

  MX_TIM2_Init();
  MX_TIM3_Init();

  // setup timers
  TIM2->CNT = 0x7FFF;
  TIM3->CNT = 0x7FFF;

  TIM2->CR1 |= TIM_CR1_CEN;
  TIM3->CR1 |= TIM_CR1_CEN;

  // read who am i register
  transmit_string("Starting IMU_init\r\n");
  who_am = imu_init();
  transmit_char(who_am);
  transmit_string("\r\n");

  // wait for button
  wait_for_button();

  // init motors
  transmit_string("Starting motors\r\n");
  init_motors();
  enable_motors();

  // init pid
  transmit_string("Starting pid\r\n");
  init_pid();

  char pbuf[100];
  while (1)
  {
    // blink green led
    GPIOC->ODR ^= (0x1 << 15);

    // not used: command parsing from uart
    char* command = get_command();

    if (string_compare(command, "f")) {
      // TODO set velocity pid to forward
    }
    if (string_compare(command, "b")) {
      // TODO set velocity pid to backward
    }
    if (string_compare(command, "n")) {
      // TODO set velocity pid to neutral/0
    }


    // debugging information
    sprintf(pbuf, "\tangle: %f", angle);
    transmit_string(pbuf);

    sprintf(pbuf, "\tpos: %d", en_pos);
    transmit_string(pbuf);

    transmit_string("\r\n");

    HAL_Delay(500);
  }
}

/** System Clock Configuration
*/
void SystemClock_Config(void)
{

  RCC_OscInitTypeDef RCC_OscInitStruct;
  RCC_ClkInitTypeDef RCC_ClkInitStruct;
  RCC_PeriphCLKInitTypeDef PeriphClkInit;//////

    /**Initializes the CPU, AHB and APB busses clocks 
    */
  RCC_OscInitStruct.OscillatorType = RCC_OSCILLATORTYPE_HSI48;
  RCC_OscInitStruct.HSI48State = RCC_HSI48_ON;
  RCC_OscInitStruct.PLL.PLLState = RCC_PLL_NONE;
  if (HAL_RCC_OscConfig(&RCC_OscInitStruct) != HAL_OK)
  {
    _Error_Handler(__FILE__, __LINE__);
  }

    /**Initializes the CPU, AHB and APB busses clocks 
    */
  RCC_ClkInitStruct.ClockType = RCC_CLOCKTYPE_HCLK|RCC_CLOCKTYPE_SYSCLK
                              |RCC_CLOCKTYPE_PCLK1;
  RCC_ClkInitStruct.SYSCLKSource = RCC_SYSCLKSOURCE_HSI48;
  RCC_ClkInitStruct.AHBCLKDivider = RCC_SYSCLK_DIV1;
  RCC_ClkInitStruct.APB1CLKDivider = RCC_HCLK_DIV1;

  if (HAL_RCC_ClockConfig(&RCC_ClkInitStruct, FLASH_LATENCY_1) != HAL_OK)
  {
    _Error_Handler(__FILE__, __LINE__);
  }

  PeriphClkInit.PeriphClockSelection = RCC_PERIPHCLK_I2C1;////
  PeriphClkInit.I2c1ClockSelection = RCC_I2C1CLKSOURCE_SYSCLK;////
  if (HAL_RCCEx_PeriphCLKConfig(&PeriphClkInit) != HAL_OK)////
  {////
    _Error_Handler(__FILE__, __LINE__);////
  }////

    /**Configure the Systick interrupt time 
    */
  HAL_SYSTICK_Config(HAL_RCC_GetHCLKFreq()/1000);

    /**Configure the Systick 
    */
  HAL_SYSTICK_CLKSourceConfig(SYSTICK_CLKSOURCE_HCLK);

  /* SysTick_IRQn interrupt configuration */
  HAL_NVIC_SetPriority(SysTick_IRQn, 0, 0);
}

/* TIM2 init function */
static void MX_TIM2_Init(void)
{

  TIM_Encoder_InitTypeDef sConfig;
  TIM_MasterConfigTypeDef sMasterConfig;

  htim2.Instance = TIM2;
  htim2.Init.Prescaler = 0;
  htim2.Init.CounterMode = TIM_COUNTERMODE_UP;
  htim2.Init.Period = 0xFFFF;
  htim2.Init.ClockDivision = TIM_CLOCKDIVISION_DIV1;
  htim2.Init.AutoReloadPreload = TIM_AUTORELOAD_PRELOAD_DISABLE;
  sConfig.EncoderMode = TIM_ENCODERMODE_TI1;
  sConfig.IC1Polarity = TIM_ICPOLARITY_RISING;
  sConfig.IC1Selection = TIM_ICSELECTION_DIRECTTI;
  sConfig.IC1Prescaler = TIM_ICPSC_DIV1;
  sConfig.IC1Filter = 0x0;
  sConfig.IC2Polarity = TIM_ICPOLARITY_RISING;
  sConfig.IC2Selection = TIM_ICSELECTION_DIRECTTI;
  sConfig.IC2Prescaler = TIM_ICPSC_DIV1;
  sConfig.IC2Filter = 0x0;
  if (HAL_TIM_Encoder_Init(&htim2, &sConfig) != HAL_OK)
  {
    _Error_Handler(__FILE__, __LINE__);
  }

  sMasterConfig.MasterOutputTrigger = TIM_TRGO_RESET;
  sMasterConfig.MasterSlaveMode = TIM_MASTERSLAVEMODE_DISABLE;
  if (HAL_TIMEx_MasterConfigSynchronization(&htim2, &sMasterConfig) != HAL_OK)
  {
    _Error_Handler(__FILE__, __LINE__);
  }

}

/* TIM3 init function */
static void MX_TIM3_Init(void)
{

  TIM_Encoder_InitTypeDef sConfig;
  TIM_MasterConfigTypeDef sMasterConfig;

  htim3.Instance = TIM3;
  htim3.Init.Prescaler = 0;
  htim3.Init.CounterMode = TIM_COUNTERMODE_UP;
  htim3.Init.Period = 0xFFFF;
  htim3.Init.ClockDivision = TIM_CLOCKDIVISION_DIV1;
  htim3.Init.AutoReloadPreload = TIM_AUTORELOAD_PRELOAD_DISABLE;
  sConfig.EncoderMode = TIM_ENCODERMODE_TI1;
  sConfig.IC1Polarity = TIM_ICPOLARITY_RISING;
  sConfig.IC1Selection = TIM_ICSELECTION_DIRECTTI;
  sConfig.IC1Prescaler = TIM_ICPSC_DIV1;
  sConfig.IC1Filter = 0x0;
  sConfig.IC2Polarity = TIM_ICPOLARITY_RISING;
  sConfig.IC2Selection = TIM_ICSELECTION_DIRECTTI;
  sConfig.IC2Prescaler = TIM_ICPSC_DIV1;
  sConfig.IC2Filter = 0x0;
  if (HAL_TIM_Encoder_Init(&htim3, &sConfig) != HAL_OK)
  {
    _Error_Handler(__FILE__, __LINE__);
  }

  sMasterConfig.MasterOutputTrigger = TIM_TRGO_RESET;
  sMasterConfig.MasterSlaveMode = TIM_MASTERSLAVEMODE_DISABLE;
  if (HAL_TIMEx_MasterConfigSynchronization(&htim3, &sMasterConfig) != HAL_OK)
  {
    _Error_Handler(__FILE__, __LINE__);
  }

}

/** Pinout Configuration
*/
static void MX_GPIO_Init(void)
{

  /* GPIO Ports Clock Enable */
  __HAL_RCC_GPIOA_CLK_ENABLE();
  __HAL_RCC_GPIOB_CLK_ENABLE();

}

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


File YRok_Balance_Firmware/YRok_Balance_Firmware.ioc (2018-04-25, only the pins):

Mcu.UserName=STM32F071CBTx
PA15.Signal=S_TIM2_CH1_ETR
PB3.Signal=S_TIM2_CH2
PB4.Signal=S_TIM3_CH1
PB5.Signal=S_TIM3_CH2
PB6.Signal=I2C1_SCL
PB7.Signal=I2C1_SDA

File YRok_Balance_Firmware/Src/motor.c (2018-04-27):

#include "motor.h"

uint32_t M1_FW = 1;
uint32_t M1_BK = 2;
uint32_t M2_FW = 12;
uint32_t STBY = 11;
uint32_t M2_BK = 10;
uint32_t M1_PWM = 14;
uint32_t M2_PWM = 15;

// Set up gpio and timers for motors.
void init_motors()
{
  RCC->AHBENR |= RCC_AHBENR_GPIOAEN | RCC_AHBENR_GPIOBEN;
  //RCC->APB1ENR |= RCC_APB1ENR_TIM2EN | RCC_APB1ENR_TIM3EN;
  RCC->APB2ENR |= RCC_APB2ENR_TIM15EN;

  //GPIOA->MODER |= (0x2 << 15*2); // E1_A

  //GPIOA->AFR[2] |= (0x2 << (15 - 8)*4);

  GPIOB->MODER |= (0x1 << M1_BK*2) | // M1_BK
                  (0x1 << M1_FW*2) | // M1_FW
                  (0x1 << M2_BK*2) | // M2_BK
                  (0x1 << STBY*2) | // STBY
                  (0x1 << M2_FW*2) | // M2_FW
                  (0x2 << M1_PWM*2) | // M1_PWM
                  (0x2 << M2_PWM*2); // M2_PWM
                  //(0x2 << 3*2); // E1_B
                  //(0x2 << 4*2) | // E2_A
                  //(0x2 << 5*2); // E2_B

  //GPIOB->AFR[0] |= (0x2 << 3*4) | (0x1 << 4*4) | (0x1 << 5*4);
  //GPIOB->AFR[0] |= (0x2 << 3*4);
  GPIOB->AFR[1] |= (0x1 << (M1_PWM - 8)*4) |(0x1 << (M2_PWM - 8)*4);

  // Select PWM mode 1, and enable OC1 preload register
  TIM15->CCMR1 |= TIM_CCMR1_OC1M_2 | TIM_CCMR1_OC1M_1 | TIM_CCMR1_OC1PE |
                  TIM_CCMR1_OC2M_2 | TIM_CCMR1_OC2M_1 | TIM_CCMR1_OC2PE;
  TIM15->CCER |= TIM_CCER_CC1E |
                 TIM_CCER_CC2E;
  TIM15->BDTR |= TIM_BDTR_MOE;
  TIM15->PSC = 0;
  TIM15->ARR = 2400; // PWM at 20kHz (Clock is 48MHz)
  TIM15->CCR1 = 0;
  TIM15->CCR2 = 0;

  // Start timer
  TIM15->CR1 |= TIM_CR1_CEN;

//  // Setup timer 2 (E1)
//  TIM2->CCMR1 |= (TIM_CCMR1_CC1S_0 | TIM_CCMR1_CC2S_0);
//  TIM2->SMCR |= (TIM_SMCR_SMS_1 | TIM_SMCR_SMS_0);
//  TIM2->CCER |= (TIM_CCER_CC1E | TIM_CCER_CC2E);
//  TIM2->ARR = 0xFFFF;
//  TIM2->CNT = 0x7FFF;
//  TIM2->CR1 |= TIM_CR1_CEN;
//
//  // Setup timer 3 (E2)
//  TIM3->CCMR1 |= (TIM_CCMR1_CC1S_0 | TIM_CCMR1_CC2S_0);
//  TIM3->SMCR |= (TIM_SMCR_SMS_1 | TIM_SMCR_SMS_0);
//  TIM3->ARR = 0xFFFF;
//  TIM3->CNT = 0x7FFF;
//  TIM3->CR1 |= TIM_CR1_CEN;
}

// Enable the standby pin on the h-bridge.
void enable_motors()
{
  GPIOB->ODR |= (0x1 << STBY);
}

// Disable the standby pin on the h-bridge.
void disable_motors()
{
  GPIOB->ODR &= ~(0x1 << STBY);
}

// Set the direction of the motor
void set_dir(int32_t motor, int32_t dir)
{
  uint32_t fw_pin = M1_FW;
  uint32_t bk_pin = M1_BK;

  if(motor == 2)
  {
    fw_pin = M2_FW;
    bk_pin = M2_BK;
  }

  switch(dir)
  {
    case MOTOR_STOP:
      GPIOB->ODR &= ~((0x1 << fw_pin) | (0x1 << bk_pin));
      break;
    case MOTOR_FORWARD:
      GPIOB->ODR |= (0x1 << fw_pin);
      GPIOB->ODR &= ~(0x1 << bk_pin);
      break;
    case MOTOR_BACKWARD:
      GPIOB->ODR |= (0x1 << bk_pin);
      GPIOB->ODR &= ~(0x1 << fw_pin);
      break;
  }
}

// Set the speed of the motor
void set_speed(int32_t motor, int32_t speed)
{
  if(speed > 0) {
    set_dir(motor, MOTOR_FORWARD);
  }
  else {
    set_dir(motor, MOTOR_BACKWARD);
    speed = -speed;
  }

  if(speed > 100) {
    speed = 100;
  }

  uint32_t tim_speed = (TIM15->ARR / 100) * speed;

  if(motor == 1)
  {
    TIM15->CCR1 = tim_speed;
  }
  else if(motor == 2)
  {
    TIM15->CCR2 = tim_speed;
  }
}

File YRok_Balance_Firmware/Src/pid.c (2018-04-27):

#include "pid.h"
#include "uart.h"
#include "imu_control.h"
#include "motor.h"

// Hz
#define PID_FREQ 500 

// for x axis
volatile int32_t gyro_y_offset = 0xFFFFFDC3;
volatile int32_t gyro_z_offset = 0xFFFFFF9A;

// PID angle control variables
volatile double angle = -1;
double angle_offset = 0;
volatile double target_angle = 0;    // target angle
volatile int32_t error = 0;         // error signal
volatile int32_t error_integral = 0;    // integrated error signal
volatile int32_t Kp = 900;            // proportional gain
volatile int32_t Ki = 15;            // integral gain
volatile double Kd = -20;            // derivative gain
int32_t clamp = 3200;
volatile int d_filtered = 0;

// PID velocity control variables
volatile double Kp2 = 5;
volatile double Ki2 = 0.01;
//volatile double Kd2 = 0;
volatile double target_speed = 0;
volatile double error_integral2 = 0;
volatile double speed = 0;
volatile double clamp2 = 1;
volatile double out_clamp2 = 5;
volatile int en_pos = 0;

// P orientation control variables
volatile double orientation = 0;
volatile double target_orientation = 0;
volatile double Kp_o = 15;
volatile int o_clamp = 35; 

// Average the gyro values over a second for calibration
void calibrate_gyro() {
  int gyro_y_sum = 0;
  int gyro_z_sum = 0;

  for (int i = 0; i < 1000; i++) {
    HAL_Delay(1);
    int gyro_y = get_gy();
    int gyro_z = get_gz();

    gyro_y_sum += gyro_y;
    gyro_z_sum += gyro_z;
  }

  gyro_y_offset = gyro_y_sum / 1000;
  gyro_z_offset = gyro_z_sum / 1000;

  transmit_string("gyro y offset: ");
  transmit_hex(gyro_y_offset);
  transmit_string("\r\n");

  transmit_string("gyro z offset: ");
  transmit_hex(gyro_z_offset);
  transmit_string("\r\n");
}

// Initialize pid loops, mainly starts timer interrupt
void init_pid() {
  if(gyro_y_offset == -1 || gyro_z_offset == -1) {
  	calibrate_gyro();
  }

  RCC->AHBENR |= RCC_AHBENR_GPIOBEN; // For profiling
  GPIOB->MODER |= (1 << 9*2); // For profiling

  RCC->APB1ENR |= RCC_APB1ENR_TIM6EN;

  TIM6->DIER |= TIM_DIER_UIE;
  TIM6->PSC = 48;
  TIM6->ARR = HAL_RCC_GetHCLKFreq() / (PID_FREQ * 48);

  NVIC_EnableIRQ(TIM6_DAC_IRQn);
  NVIC_SetPriority(TIM6_DAC_IRQn, 0);

  TIM6->CR1 |= TIM_CR1_CEN;
}

// Update function for angle control
int PID_update(int32_t accel_x, int32_t gyro_y) {
  gyro_y -= gyro_y_offset;
  gyro_y *= -1;

  angle = ((0.98) * (angle + (((gyro_y / 131.0) / 100.0))) + (0.02 * (accel_x / 182.0)));

  error = target_angle - (int32_t) (angle - angle_offset);

  /// Calculate integral portion of PI controller, write to "error_integral" variable
  error_integral += Ki * error;

  /// Clamp the value of the integral to a limited positive range
  if (error_integral < -clamp) {
    error_integral = -clamp;
  }
  if (error_integral > clamp) {
    error_integral = clamp;
  }

  d_filtered = (d_filtered * 7) / 8 + gyro_y / 8;

  /// Calculate proportional portion, add integral and write to "output" variable
  int32_t output = Kp * error + error_integral + Kd * (d_filtered / 131.0);

  /// Divide the output into the proper range for output adjustment
  output /= 64;

  /// Clamp the output value between 0 and 100
  if (output < -100) {
    output = -100;
  }
  if (output > 100) {
    output = 100;
  }

  return output;
}

// Update function for velocity control
void PI_update2() {
  int32_t d_dist = TIM2->CNT - 0x7FFF;
  TIM2->CNT = 0x7FFF;
  speed = speed * 0.95 + d_dist * 0.05;
  en_pos += d_dist;

  double error2 = target_speed - speed;

  error_integral2 += Ki2 * error2;

  if(error_integral2 > clamp2) {
  	error_integral2 = clamp2;
  }
  if(error_integral2 < -clamp2) {
  	error_integral2 = -clamp2;
  }

  double output = Kp2 * error2 + Ki2 * error_integral2;
  if(output > out_clamp2) {
  	output = out_clamp2;
  }
  if(output < -out_clamp2) {
  	output = -out_clamp2;
  }

  target_angle = output;
}

// Update function for orientation control
int orientation_update(int32_t gyro_z) {
	gyro_z -= gyro_z_offset;
	orientation = orientation + gyro_z * (0.004375) / 250.0;

	double error_orientation = target_orientation - orientation;

	int output = (int) (error_orientation * Kp_o);

	if(output > o_clamp) {
		output = o_clamp;
	}
	if(output < -o_clamp) {
		output = -o_clamp;
	}

	return output;
}

void TIM6_DAC_IRQHandler(void) {
  // For profiling, hook PB9 to scope to time interrupt length
  GPIOB->ODR |= (1 << 9);

  int32_t accel_x = get_ax();
  int32_t gyro_y = get_gy();
  int32_t gyro_z = get_gz();

  int turn = orientation_update(gyro_z);

  PI_update2();

  int32_t pwm_l = -PID_update(accel_x, gyro_y);
  int32_t pwm_r = pwm_l;

  pwm_l -= turn;
  pwm_r += turn;

  set_speed(MOTOR_LEFT, pwm_l);
  set_speed(MOTOR_RIGHT, pwm_r);

  GPIOB->ODR &= ~(1 << 9); // For profiling
  TIM6->SR &= ~TIM_SR_UIF;
}

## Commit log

2018-03-29 Added Kicad files, and chassis files.
    [Balance_Bot.scad, Board_2d.scad, Control_Board.kicad_pcb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]
2018-03-29 Removed irrelevant chassis files, got newer copies of others.
    [Balance_Bot.scad, Encoder.scad, Encoder_Test_Fixture.scad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]
2018-04-10 Updated chassis, added Control Board Schematic, and added led blinking to firmware.
    [Balance_Bot.scad, Yellow_Motor.scad]
2018-04-11 Added tabs and captive bolts.
    [Balance_Bot.scad, Encoder.scad]
2018-04-11 Added basic motor init.
2018-04-12 Chassis is 99% done, just needs dimension checking.
    [Balance_Bot.scad, Global_Defs.scad]
2018-04-18 Got uart echo working
2018-04-18 Encoders working with hal. Some issues with extra counts sometimes.
    [YRok_Balance_Firmware.ioc, main.c, motor.c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]
2018-04-18 Added the IMU control .c and .h files
2018-04-18 added newlines to uart
2018-04-18 made small changes for who_am_i imu
2018-04-18 IMU should be working now, but haven't been able to check
2018-04-20 Able to get the x of the accelerometer using function get_ax
2018-04-21 Now can also read the two bytes for the Gyroscope's Y
2018-04-21 Added some gyro stuff to pid.
2018-04-26 Final Chassis
    [Balance_Bot.scad, Encoder_Wheel.scad, Yellow_Motor.scad]

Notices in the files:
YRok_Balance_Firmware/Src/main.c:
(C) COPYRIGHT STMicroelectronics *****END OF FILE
